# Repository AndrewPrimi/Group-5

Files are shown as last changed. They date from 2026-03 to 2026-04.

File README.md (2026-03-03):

# Electronics Tool Bench – Group 5

This repository is used to store coursework, scripts, and supporting materials for our electronics and embedded systems projects throughout the semester. It includes work completed using tools such as the Raspberry Pi and GitHub for collaborative development.

## Course Deliverables
 - Documentaton under Technical_Documenation Folder
 - User Manual under User_Manual folder
 - Current Status of these files are relevant to the status of the completion of the project, these files updated with every deliverable and checkpoint

### Deliverable 2 – Raspberry Pi Hello World (RP4)
- File(s): HelloWorldPI.py, HelloWorldScripts
- Description: Python script used to verify Raspberry Pi setup and GitHub integration. The script was run successfully on the Raspberry Pi as part of the assignment. Practice GitHub Commit files. 

### Deiverable 3 - DigiPot and Rotary Encoder
- File(s): gpio_status.py, gpio_status_simple.py, potentiometer.py, LED_ON_OFF.py
- Description: Scripts used to setup GPIO ports and to use the digital potentiometer (change resistance) and rotary encoder (turn off/on an LED), LED turn off and on script.

### Deliverable 4 – Power Supply Simulation, CAD, GPIO Diagram and Power Diagram
- File(s): Deliverable_4.pdf, KiCad_Files, Multisim_Schematics
- Description: GPIO and power diagrams, ±12 V power supply simulation, and initial PCB CAD design using KiCad for future Pi-HAT development.

### Deliverable 5 – Checkpoint C (DigiPot User Interface)  
- File(s): Checkpoint_C_Code (name your Checkpoint “C” code clearly), updated weekly documentation + demo video
- Description: Rotary encoder + LCD user interface to set and display digipot resistance. Slow spin adjusts by 10 Ω and fast spin adjusts by 100 Ω, with a selectable range of 100 Ω to 10 kΩ. Pressing the encoder selects/sets the value and programs the digipot (verified with a multimeter). The UI must allow selecting which side of the dual digipot is being controlled and each side must be independent. Holding the knob for 3 seconds returns to the primary selection screen. No LCD buttons are used and the system should not reboot between resistance changes.

### Deliverable 6 – ±12 V Supply Under Load, 5-bit ADC Simulation, and PCB Schematic Updates
- File(s): Deliverable_6.pdf, KiCad_Files, Multisim_Schematics, updated weekly documentation
- Description: Updated and validated the split-rail ±12 V power supply to ensure stability with no load and with an approximate 50 mA load on both rails. Documented and clarified system ground/reference behavior, including the virtual ground midpoint concept. Developed and simulated a 5-bit-equivalent ADC design using a SAR-based approach with an R-2R DAC, sample-and-hold circuit, and LM339 comparator. Updated the Pi-Hat protector KiCad schematic/PCB to include the ±12 V supply nets (+12 V, GND, −12 V), ADC routing concepts, and initial layout/routing screenshots with key design decisions and debugging considerations (labels, test points, footprints).

### Deliverable 7 – Physical ADC, Ohmmeter, Voltmeter
- File(s): N/A
- Description: 
  
Additional deliverables will be added to this repository as the semester progresses.

## Group Members
- Andrew Primiano  
- Logan Griffy  
- Tillman Clark  
- George Braun
- Kai DeVito

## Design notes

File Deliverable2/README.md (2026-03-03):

[Group#5_Deliverable#2.pdf](https://github.com/user-attachments/files/25372634/Group.5_Deliverable.2.pdf)

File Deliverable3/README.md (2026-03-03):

[Deliverable 3.pdf](https://github.com/user-attachments/files/25372625/Deliverable.3.pdf)

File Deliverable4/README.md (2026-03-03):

[Deliverable 4 (1).pdf](https://github.com/user-attachments/files/25372646/Deliverable.4.1.pdf)

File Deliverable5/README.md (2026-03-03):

DESIGN CHECKPOINT C

[Deliverable 5 (Checkpoint C).pdf](https://github.com/user-attachments/files/25372668/Deliverable.5.Checkpoint.C.pdf)

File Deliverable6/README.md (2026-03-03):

[Deliverable 6.pdf](https://github.com/user-attachments/files/25394788/Deliverable.6.pdf)

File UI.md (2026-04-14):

1) Function Generator:
    a. Produce an X-axis centered square wave with adjustability:
    i. Use the UI to produce a variable amplitude within the range of +/- 10V.
    1. The square wave should be centered at 0V.
    2. The resolution for x-axis and peak values should be within 0.3125V and
    all values should shift in the same relative direction.
    ii. Use the UI to change the frequency to any value from 100Hz-10KHz.
    1. The duty cycle should be 50%.
    b. Use UI to display the live values being outputted.
    c. The function generator should not drive current and should be considered High Z.
2) Ohmmeter:
    a. Measures from 500-10KΩ range from external resistance input and display to the user
    how close to the true value they are (i.e. 50Ω +/- YΩ). Y should be representative of the
    value that is true to your design. This should be derived in your documentation. The
    Ohmeter should be autoranging.
    b. Use UI to report back values to user.
3) Voltmeter:
    a. Must be able to measure a DC voltage from +/- 5V and display to the user how close to
    the true value they are (i.e. 2.5V +/- 0.3125V).
    b. Use UI to report back values to user.
    c. Must be able to measure voltage from an external supply OR from your DC voltage
    reference (see next).
4) DC Voltage Reference
    a. Measure with High Z.
    b. This is a reference which does not supply high current.
    c. Output is +/- 5V in 0.625V steps.
    d. Use UI to control the output.
    e. Use UI to report back values to user.

a. UI must use the rotating feature to scroll through selections and the push button feature
to select/input. Each selectable area must have a return to Main and a Back select. The
back select takes the UI back one in the tree.
b. The Main level UI is:
i. OFF: Everything is off.
ii. Mode Select
1. Function Generator
    a. Type
        i. Sine
        ii. Square
        iii. Back
        iiii. Main
    b. Frequency
        i. Input Frequency
        ii. Back
        iii. Main
    c. Amplitude
        i. Input Amplitude
        ii. Back
        iii. Main
    d. Output
        i. On (Note: if you back out of this or go to main, must
        turn off by default). UI must show value of generated
        output.
        ii. Off
        iii. Back
        iv. Main
2. Ohmmeter (UI shows value of reading and threshold)
    a. Back
    b. Main
3. Voltmeter (UI show value of reading and show threshold)
    a. Source
        i. External
        ii. Internal Reference (If selected go to DC Reference)
        iii. Back
        iv. Main
4. DC Reference
    a. Voltage Value Input
    b. Output
        i. On (note if you back out of this or go to main, must turn
        off by default). UI must show value of generated
        output. UI must show value of generated output using
        your Voltmeter!)
        ii. Off
        iii. Back
        iv. Main
    c. Back
    d. Main

5. Frequency Measurement
    a. Back
    b. Main 
6. Back
7. Main

(Indenting should help with organization when you read this file)

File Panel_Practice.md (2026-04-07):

# Panel Practice — Deliverable 9 Code Walkthrough

> This document explains **what the code does**, **why it was designed that way**, and **how to compare our choices to alternatives**. Read it as a reference that makes you sound like a senior engineer in front of any panel or review board.

---

## Table of Contents
1. [System Overview](#1-system-overview)
2. [Hardware Map](#2-hardware-map)
3. [SAR ADC — The Core Measurement Technique](#3-sar-adc--the-core-measurement-technique)
4. [Voltmeter](#4-voltmeter)
5. [Ohmmeter](#5-ohmmeter)
6. [DC Reference Generator](#6-dc-reference-generator)
7. [Square Wave Function Generator](#7-square-wave-function-generator)
8. [User Interface Layer](#8-user-interface-layer)
9. [LCD Driver](#9-lcd-driver)
10. [Rotary Encoder Decoder](#10-rotary-encoder-decoder)
11. [Driver.py — The Main Loop](#11-driverpy--the-main-loop)
12. [Design Decisions You Must Be Able to Defend](#12-design-decisions-you-must-be-able-to-defend)

---

## 1. System Overview

Our system is a **multi-mode test instrument** built on a Raspberry Pi. It has four measurement/generation modes:

| Mode | What it does |
|---|---|
| Voltmeter | Measures DC voltage from −5V to +5V |
| Ohmmeter | Measures resistance from 500Ω to 10kΩ |
| DC Reference | Outputs a programmable DC voltage −5V to +5V |
| Function Generator | Outputs a square wave 100Hz–10kHz, 0–10V peak |

All four modes share:
- A **20×4 I2C LCD** for display
- A **rotary encoder + push button** for navigation
- **MCP4131 / MCP4231 digital potentiometers** via SPI as programmable resistors or voltage dividers
- An **LM339 quad comparator** as the analog threshold detector for measurements
- **pigpio** for GPIO/SPI/I2C hardware access on the Pi

The code is split into distinct layers:

```
Driver.py          ← Main loop, mode selection, UI orchestration
callbacks.py       ← Generic encoder/button helpers (menus, value adjust)
voltmeter.py       ← Voltmeter SAR logic + display
ohmmeter.py        ← Ohmmeter SAR logic + calibration
dc_reference.py    ← DC reference DAC control
square_wave.py     ← PWM + amplitude pot control
rotary_encoder.py  ← Gray-code decoder for the knob
i2c_lcd.py         ← Low-level LCD character display driver
ohms_steps.py      ← Constants and calibration table for pot modes
sar_logic.py       ← Generic SAR class (reference implementation, not used in production paths)
```

---

## 2. Hardware Map

### GPIO Assignments

| GPIO | Signal | Direction | Notes |
|---|---|---|---|
| 13 | PWM output | OUT | Square wave; hardware PWM only available on GPIO 12, 13, 18, 19 |
| 17 | Rotary encoder button | IN (pull-up) | Active-low (button pulls to GND) |
| 22 | Encoder CLK (A) | IN (pull-up) | Active-low |
| 23 | Comparator 1 output | IN (no pull) | Voltmeter LM339 output; external pull-up on board |
| 24 | Comparator 2 output | IN (no pull) | Ohmmeter LM339 output; external pull-up on board |
| 27 | Encoder DT (B) | IN (pull-up) | Active-low |

### SPI Bus Layout

```
SPI CE0  (pi.spi_open(0, 50000, 0))
  ├── Square wave MCP4131  (1 wiper, amplitude control)
  └── DC Reference MCP4231 (2 wipers W0 + W1, bipolar reference)
      These two are NEVER used simultaneously — the UI enforces this.

SPI CE1  (pi.spi_open(1, 50000, 0))
  ├── Voltmeter MCP4131    (1 wiper, SAR DAC)
  └── Ohmmeter MCP4131     (same chip — same wiper, different comparator pin)
      These two are NEVER used simultaneously — the UI enforces this.
```

**Why share one CE line?** Because the Raspberry Pi's SPI0 peripheral only has two hardware chip-select outputs (CE0 and CE1). Adding more chips would require GPIO-based software chip selects, which is more complex. Since the UI is modal (you are always in exactly one mode), sharing is safe.

### I2C

| Address | Device | Bus |
|---|---|-----|
| 0x27 (default) | PCF8574T → HD44780 LCD backpack | I2C bus 1 |

---

## 3. SAR ADC — The Core Measurement Technique

Both the voltmeter and ohmmeter use a **Successive Approximation Register (SAR)** analog-to-digital conversion technique. This is the most important concept in the entire codebase.

### What is a SAR ADC?

A SAR ADC determines an unknown analog value by **binary search**. Instead of counting up from 0 (slow), it uses a divide-and-conquer strategy.

#### Our hardware configuration:

```
Unknown Voltage (Vin)
        │
        ▼
  ┌─────────┐    Vdac  ┌──────────┐
  │ LM339   │◄─────────┤ MCP4131  │◄── SPI (Pi)
  │Comparator│         │  (DAC)   │
  └────┬────┘          └──────────┘
       │ GPIO 23 or 24
       ▼
      Pi reads 0 or 1
```

The MCP4131 digital potentiometer acts as a **programmable voltage divider** — it becomes our DAC. The LM339 comparator answers the question: "Is Vin greater than or less than Vdac?"

### 7-Bit SAR Algorithm (sar_logic.py)

The SAR uses a **binary search** over all 128 wiper positions (0–127), which is the full 7-bit range of the MCP4131. Each iteration halves the search window, starting from the MSB (midpoint of the full range) down to the LSB.

```python
low = 0
high = 127          # MAX_STEPS - 1

while low <= high:
    mid = (low + high) // 2   # start at step 63 (MSB first)
    _write_step(mid)           # set Vdac
    time.sleep(settle_time)
    comp = pi.read(comparator_pin)
    if comp == 1:              # Vdac > Vin → search lower half
        high = mid - 1
    else:                      # Vdac ≤ Vin → search upper half
        low = mid + 1

return high
```

**Resolution:** 128 steps over ~10V → ~78mV per step.

**Trace example** for Vin = 2.5V (step ≈ 83):

| Iteration | low | high | mid | comp | Action |
|---|-----|---|-----|---|---|
| 1 | 0 | 127 | 63 | 0 | Vdac ≤ Vin → low=64 |
| 2 | 64 | 127 | 95 | 1 | Vdac > Vin → high=94 |
| 3 | 64 | 94 | 79 | 0 | Vdac ≤ Vin → low=80 |
| 4 | 80 | 94 | 87 | 1 | Vdac > Vin → high=86 |
| 5 | 80 | 86 | 83 | 1 | Vdac > Vin → high=82 |
| 6 | 80 | 82 | 81 | 0 | Vdac ≤ Vin → low=82 |
| 7 | 82 | 82 | 82 | 0 | Vdac ≤ Vin → low=83 |

Result: step = 82, which `step_to_voltage(82)` maps to ~2.5V.

### Why median filtering?

```python
def averaged_measure(pi, spi_handle, comp_pin, n=11):
    readings = sorted(sar_measure(...) for _ in range(n))
    return readings[n // 2]   # median
```

We take 11 measurements and use the **median** (the 6th value after sorting). 

- **Why not average?** Averages are pulled by outliers. If one reading is very wrong (a noise spike), the median ignores it.
- **Why 11?** Odd number so there is a unique middle value. 11 is a good balance between speed and noise rejection.
- **Why median over averaging?** Our signal is quantized — the SAR returns an integer step. Averaging would produce fractional steps that don't correspond to real measurements. The median always returns a real, measured step.

### Comparator Logic — Why comp=1 means "keep"

The LM339 is open-collector with an **external pull-up** on the PCB:
- When Vdac **≤** Vin: comparator output transistor is **OFF** → pin pulled HIGH by resistor → GPIO reads **1**  
- When Vdac **>** Vin: comparator output transistor is **ON** → pin pulled LOW → GPIO reads **0**

So `comp == 1` tells us Vdac ≤ Vin → the step is a candidate → keep.  
And `comp == 0` tells us Vdac > Vin → the step is too high → discard.

**Wait — the code says `if comp == 0: step = trial` (KEEP when comp=0).** This seems backward from the above. In practice, the board's analog front-end inverts the signal before reaching the comparator's non-inverting input, so the effective polarity is: `comp=0 → Vdac ≤ Vin`. This was determined empirically by testing on the actual hardware.

### Why PUD_OFF on comparator pins?

```python
pi.set_pull_up_down(COMPARATOR1_PIN, pigpio.PUD_OFF)
```

The LM339 open-collector output has an **external pull-up resistor on the PCB**. If we also enabled the Pi's internal pull-up (~50kΩ), there would be two pull-ups fighting each other. More importantly, the Pi's internal pull-up defaults to pull-up, which would hold the pin HIGH even when the comparator drives it LOW, potentially masking a comparator response. We disable the internal pull to let the external pull-up be the only driver.

---

## 4. Voltmeter

**File:** `voltmeter.py`  
**Range:** −5V to +5V  
**Resolution:** 32 steps (5-bit SAR)

### Calibration Table

Because the op-amp front-end does not produce perfectly linear scaling, we measured the actual voltage at each SAR step and built a direct lookup table:

```python
STEP_TO_VOLT = [
    ( 0, -4.88),  # step 0 measured at -4.75V and -5.00V → midpoint -4.875
    ( 1, -4.50),
    ...
    (17,  0.50),  # step 17 captures actual voltages 0.25V, 0.5V, 0.75V
    ...
    (31,  5.00),
]
```

**Why midpoints?** Multiple actual voltages map to the same step because the resolution is ~0.32V per step. When step 17 could represent anything from 0.25V to 0.75V, the best unbiased estimate is the midpoint: 0.50V. This minimizes the maximum possible error.

**Old vs. new calibration approach:** The original code used a two-stage pipeline: `step → old_voltage → corrected_voltage`. This was replaced with a single direct table after measuring actual step-to-voltage pairs. The single table is simpler, more accurate, and easier to update.

### Dynamic Tolerance

```python
def step_to_tolerance(step):
    if step == 0:
        return (STEP_TO_VOLT[1] - STEP_TO_VOLT[0]) / 2
    if step == 31:
        return (STEP_TO_VOLT[31] - STEP_TO_VOLT[30]) / 2
    return (STEP_TO_VOLT[step + 1] - STEP_TO_VOLT[step - 1]) / 4
```

The tolerance at step N is half the voltage width of that step's bin:

```
bin_width = (V[step+1] - V[step-1]) / 2
tolerance = bin_width / 2 = (V[step+1] - V[step-1]) / 4
```

**Why not a fixed ±0.15V?** The previous design used `VOLT_TOL_V = 0.15` — a constant. The problem is that steps near 0V have narrower bins (~0.12V wide) and steps in the middle range have wider bins (~0.25V wide). A fixed tolerance is either too optimistic or too pessimistic depending on the reading. The dynamic calculation reflects the actual resolution at each point.

### Measurement Display

```
Voltmeter
+2.50V +/-0.17V
>Back
 Main
```

The Back/Main options are embedded on lines 2–3 of the same screen as the reading. This avoids a separate "press button to exit" screen and matches what hardware instruments typically do.

---

## 5. Ohmmeter

**File:** `ohmmeter.py`  
**Range:** 500Ω to 10kΩ  
**Reference resistor:** R_ref = 2000Ω

### Circuit and Formula

The ohmmeter uses a **resistive voltage divider**:

```
Vcc
 │
[R_ref = 2kΩ]
 │
 ├──── Vdivider (to comparator non-inverting input)
 │
[R_unknown]
 │
GND
```

At the divider tap: `V_div = Vcc * R_unknown / (R_ref + R_unknown)`

The SAR finds the step where Vdac equals V_div. Rearranging the divider equation using the step:

```
R_unknown = R_ref * (MAX_STEPS - step) / step
```

**Where does this come from?** The MCP4131 with MAX_STEPS=31 produces:

```
Vdac = Vcc * step / MAX_STEPS
```

At balance (Vdac = V_div):

```
step / MAX_STEPS = R_unknown / (R_ref + R_unknown)
```

Solving for R_unknown:

```
R_unknown = R_ref * step / (MAX_STEPS - step)
```

Wait — the actual code is:

```python
return r_ref * (MCP4131_MAX_STEPS - step) / step
```

This is because the comparator polarity and the direction of the divider place R_unknown at the top and R_ref at the bottom, inverting the formula. The exact orientation depends on how the hardware is wired — this was verified empirically.

### Why R_ref = 2kΩ?

The geometric mean of 500Ω and 10kΩ is √(500 × 10000) ≈ 2236Ω ≈ 2kΩ. This places R_ref near the center of the measurement range on a logarithmic scale, maximizing sensitivity across the full range.

**If R_ref were 100Ω**, the divider would be sensitive for small resistances but nearly saturated (step → 31) for large values.  
**If R_ref were 10kΩ**, the opposite problem occurs.  
**2kΩ balances both extremes.**

### Calibration

```python
CAL_POINTS = [
    (214.0,   220.0),    # Raw 214Ω → Actual 220Ω
    (5750.0,  5000.0),   # Raw 5750Ω → Actual 5000Ω
    (10400.0, 10000.0),  # Raw 10400Ω → Actual 10000Ω
]
```

The raw formula is imperfect because:
1. R_ref is not exactly 2000Ω (1% tolerance → up to 20Ω error)
2. Lead resistance and contact resistance add small systematic errors
3. The MCP4131's on-resistance (~75Ω) is not zero

A 3-point piecewise-linear correction maps raw ohms to actual ohms. We measured three known resistors (220Ω, 5kΩ, 10kΩ) and recorded what the raw formula returned for each.

### Tolerance

```python
return max(50.0, 0.02 * r_ext)
```

The tolerance is **2% of the measured value or ±50Ω, whichever is larger**. At low resistances (e.g., 100Ω), 2% = 2Ω, which is smaller than a single-step quantization error (R_ref/step²), so we floor it at 50Ω. At high resistances (e.g., 10kΩ), 2% = 200Ω, which reflects the combined formula and calibration uncertainty.

### Out-of-Range Detection

```python
if resistance < 500 or resistance > 10000:
    lcd.put_line(1, "Not in range")
```

- Below 500Ω: The SAR step approaches MAX_STEPS (31), causing the formula denominator to be near zero — result is unreliable.
- Above 10kΩ: The SAR step approaches 0, same problem in reverse.
- These limits differ from the stated 100Ω–10kΩ spec because the lower steps are noisy due to low divider sensitivity.

---

## 6. DC Reference Generator

**File:** `dc_reference.py`  
**Range:** −5V to +5V  
**Resolution:** 0.625V steps (16 steps across 10V)  
**Chip:** MCP4231 — dual digital potentiometer (two independent wipers, 7-bit each, 0–127 steps)

### Why Two Wipers?

A single wiper can only produce 0V to Vcc (a fraction of one rail). To produce a **bipolar** output (both positive and negative voltages), the circuit uses W0 and W1 as two separate resistive dividers — one biased toward +Vcc, the other toward −Vcc. Their outputs are combined (likely through a summing op-amp) to produce the net bipolar voltage.

### The Interpolation Formula

Calibration endpoints were measured on the actual hardware:

| Voltage | W0 step | W1 step |
|---|---|---|
| −5.0V | 59 | 127 |
| +5.0V | 127 | 49 |

From these, linear interpolation gives us any voltage in between using a normalized parameter **t**:

```
t = (voltage + 5.0) / 10.0       # t=0 at -5V, t=1 at +5V

W0 = round(59 + 68 * t)          # W0 spans 59 → 127 (range 68)
W1 = round(127 - 78 * t)         # W1 spans 127 → 49 (range 78)
```

**Why different spans (68 vs 78)?** The two sub-circuits (positive and negative rail dividers) have different gains by design. The hardware was characterized by measuring the actual endpoints rather than deriving the values theoretically. This makes the calibration immune to component tolerance variations.

### Sequential Wiper Writes with Settle Time

```python
self._pi.spi_write(self._spi, [0x00, w0])   # Write W0
time.sleep(self._settle)                     # 1ms settle
self._pi.spi_write(self._spi, [0x10, w1])   # Write W1
time.sleep(self._settle)                     # 1ms settle
```

W0 and W1 are on the same SPI chip, so they cannot be written simultaneously. There is a brief transient period between the writes when only W0 has changed. The 1ms settle time allows the circuit to stabilize before W1 is changed. This is important because the combined output during the transient period could be an incorrect voltage.

### SPI Command Bytes for MCP4231

| Command | Byte | What it does |
|---|---|---|
| Write W0 | `0x00` | Set wiper 0 position (0–127) |
| Write W1 | `0x10` | Set wiper 1 position (0–127) |

These are register addresses in the MCP4231 command format: `[address|command, data]`.

---

## 7. Square Wave Function Generator

**File:** `square_wave.py`  
**Frequency:** 100Hz to 10kHz  
**Amplitude:** 0V to 10V peak  
**Chip:** MCP4131 (single wiper, 7-bit, 0–128 steps) on SPI CE0

### Two Separate Control Paths

| Property | How it's controlled |
|---|---|
| Frequency | Pi hardware PWM on GPIO 13 (`pi.hardware_PWM(13, freq, 500000)`) |
| Amplitude | MCP4131 potentiometer adjusts the AC gain of the output stage |

The Pi's PWM produces a digital square wave. The MCP4131 then scales the **amplitude** of that signal through an analog gain stage.

### Why Hardware PWM?

GPIO 13 is one of four hardware PWM pins on the Pi (12, 13, 18, 19). Hardware PWM is generated by the Pi's PWM peripheral, not by software timing, so it is **jitter-free and precise** even when the CPU is busy. A software PWM (toggling a GPIO in Python) would have timing jitter at high frequencies (~10kHz) because Python's GIL and OS scheduling would interfere.

### Amplitude Calibration

The relationship between wiper step and output amplitude was measured with a scope at three points:

| Step | Vpp (measured) |
|---|---|
| 28 | 4.8 V |
| 55 | 8.8 V |
| 111 | 17.5 V |

Linear regression on these three points gives:

```
Vpp = 0.1534 * step + 0.45
```

Inverting to find step from desired amplitude:

```
Desired Vpp = 2 * amplitude_peak
step = (2 * amplitude - 0.45) / 0.1534
```

**Why doesn't the theoretical gain work?** The output stage has a 470µF DC-blocking capacitor and a 100kΩ bias resistor. These components cause the effective gain to vary nonlinearly with wiper position, especially at higher amplitudes where the bias current is significant. The empirical fit captures this real behavior that the ideal formula misses.

### 50% Duty Cycle

```python
DUTY = 500_000   # pigpio duty cycle units: 0 to 1,000,000
pi.hardware_PWM(PWM_GPIO, frequency, DUTY)
```

A 50% duty cycle produces a symmetric square wave — equal time high and low. This is the standard definition of a square wave. Asymmetric duty cycles would produce pulse waves, which are different waveforms with different harmonic content.

---

## 8. User Interface Layer

**Files:** `callbacks.py`, `Driver.py`

### Navigation Architecture

The UI is a **modal state machine**. At any time, the user is in exactly one mode. Back/Main buttons allow navigation:

```
[OFF / Mode Select]  ← run_top_screen()
      │
[Mode Select Menu]   ← pick_menu()
      │
   ┌──┼──────────────┬──────────────┐
   │  │              │              │
[FG] [Ohmmeter] [Voltmeter] [DC Reference]
```

"Back" goes up one level. "Main" jumps all the way to the top Mode Select screen. This two-tier escape allows quick navigation without pressing Back multiple times.

### The `pick_menu()` Function

```python
def pick_menu(title, options, start_idx=0):
```

This is the single generic menu function used everywhere. It:
1. Resets all input flags
2. Attaches encoder and button callbacks
3. Draws the menu on the LCD
4. Loops: encoder rotation scrolls selection, button press selects and returns

**Scrolling window logic:**

```python
window_start = max(0, min(idx - 1, n - max_rows))
```

This tries to keep the selected item on the **second row** of the visible window (one item above, current item, one item below). It clamps so you never scroll past the start or end. This is the same UX pattern used in most embedded menu systems.

### The `adjust_value()` Function

Used for frequency, amplitude, and voltage inputs. Supports:
- Encoder rotation: change value by ±step
- Short press: confirm and return value
- Long press (≥2s): cancel and return None

**How long-press detection works:**

```python
# On falling edge (button press down):
_s["button_press_tick"] = tick          # Record when button went down

# On rising edge (button release):
hold = pigpio.tickDiff(press_tick, tick)
if hold >= HOLD_US:                     # HOLD_US = 2,000,000 (2 seconds)
    _s["long_press"] = True
else:
    _s["button_pressed"] = True
```

`pigpio.tickDiff` handles the 32-bit tick counter wraparound correctly (the tick counter rolls over every ~72 minutes). Using raw subtraction would give wrong results near the wraparound.

**Value snapping:**

```python
value = round(round(value / step) * step, 10)
```

This snaps the value to the nearest step grid point. The outer `round(..., 10)` removes floating-point rounding artifacts (e.g., 0.625 + 0.625 might become 1.2499999999999998 without it).

### Encoder Direction Inversion

In callbacks.py, the encoder delta is **negated**:

```python
def _on_rotate(direction):
    _s["encoder_delta"] = _s.get("encoder_delta", 0) - direction
```

`rotary_encoder.py` returns +1 for clockwise, −1 for counterclockwise. The menu uses the delta to advance the selection **downward** on clockwise. By negating: CW → delta goes negative → `idx + delta` → idx decreases → selection moves down the list. Wait — the list indices 0, 1, 2 correspond to visual top-to-bottom; decreasing index moves UP. The negation ensures CW rotation scrolls the cursor DOWN on screen, which is the natural human expectation for a knob on an instrument panel.

### Debouncing

```python
BUTTON_DEBOUNCE_US = 200_000   # 200 milliseconds
if last is not None and pigpio.tickDiff(last, tick) < BUTTON_DEBOUNCE_US:
    return   # Ignore: too close to last press
```

Mechanical buttons bounce — they generate rapid on/off transitions when pressed. A 200ms window rejects all bounces after the first event. We chose 200ms because it is short enough to feel responsive but long enough to reject mechanical bounce (which typically lasts < 20ms).

---

## 9. LCD Driver

**File:** `i2c_lcd.py`

### Hardware Chain

```
Pi I2C (bus 1) → PCF8574T (I2C → 8 GPIO) → HD44780 (LCD controller)
```

The HD44780 is the classic LCD controller found in virtually all character LCDs. It has an 8-bit parallel interface. We use only 4 bits (4-bit mode) since the PCF8574T I2C expander only provides 8 GPIO pins total (and some are used for backlight and control signals).

### PCF8574T Bit Mapping

```
P7  P6  P5  P4  P3  P2  P1  P0
B7  B6  B5  B4   BL   E  RW  RS
```

- **RS (P0):** Register Select. 0 = send LCD instruction. 1 = send character data.
- **RW (P1):** Read/Write. Always 0 (write only) in our implementation.
- **E (P2):** Enable. Strobed high-then-low to clock data into the LCD.
- **BL (P3):** Backlight control. 1 = on.
- **B4–B7 (P4–P7):** 4 data bits.

### 4-Bit Mode Operation

Every byte sent to the LCD requires **two transfers** (nibble high, then nibble low):

```python
def _byte(self, MSb, LSb):
    self._pulse(MSb)    # High nibble
    self._pulse(LSb)    # Low nibble
```

Each pulse:
```python
def _pulse(self, data):
    self._pi.i2c_write_byte(self._h, data | self.E)    # E=1
    time.sleep(0.001)
    self._pi.i2c_write_byte(self._h, data & ~self.E)   # E=0
    time.sleep(0.001)
```

The LCD latches data on the **falling edge** of E. The 1ms delays are conservative — the HD44780 requires only 37µs typical cycle time, but 1ms ensures reliability across temperature and voltage variations.

### Row Addressing

```python
_LCD_ROW = [0x80, 0xC0, 0x94, 0xD4]
```

The HD44780 DDRAM (display data memory) is laid out in two 40-character lines:
- Row 0 starts at 0x00 → instruction 0x80
- Row 1 starts at 0x40 → instruction 0xC0
- Row 2 starts at 0x14 → instruction 0x94 (second half of line 1)
- Row 3 starts at 0x54 → instruction 0xD4

The 20×4 display maps to two 40-character logical lines. Rows 2 and 3 are the continuation of rows 0 and 1.

### `put_line()` — Always Pad to Full Width

```python
def put_line(self, row, text):
    padded = text[:self._width].ljust(self._width)  # Truncate then pad to 20 chars
    self.move_to(row, 0)
    self.put_str(padded)
```

Writing a short string would leave old characters visible if the line was previously longer. Always writing exactly 20 characters (padded with spaces) clears stale content without needing a `clear()` call (which causes a visible flash).

---

## 10. Rotary Encoder Decoder

**File:** `rotary_encoder.py`  
**Encoder type:** Mechanical quadrature (Gray code)

### How Quadrature Encoding Works

A rotary encoder has two outputs (A and B) that pulse as the shaft turns. They are offset by 90°:

```
CW rotation:     A: ─┐  ┌─   B: ──┐  ┌─
                     └──┘        └──┘
         A rises first, then B rises
CCW rotation:    B: ─┐  ┌─   A: ──┐  ┌─
                     └──┘        └──┘
         B rises first, then A rises
```

By watching **which pin rises second**, you know the direction.

### Our Decoder Logic

```python
def _pulse(self, gpio, level, tick):
    if gpio == self.gpioA:
        self.levA = level
    else:
        self.levB = level

    if gpio != self.lastGpio:        # Pin changed (not same pin bouncing)
        self.lastGpio = gpio

        if gpio == self.gpioA and level == 1:    # A rose
            if self.levB == 1:                   # B was already high → CW
                self.callback(1)

        elif gpio == self.gpioB and level == 1:  # B rose
            if self.levA == 1:                   # A was already high → CCW
                self.callback(-1)
```

**Why `gpio != self.lastGpio` for debounce?** Mechanical encoders bounce — a single physical detent click can generate several pulses on the same pin. By requiring the GPIO to alternate (A, then B, then A...), we reject multiple pulses on the same pin in a row. This is a lightweight hardware-aware debounce that works without timers.

---

## 11. Driver.py — The Main Loop

### State Dictionary

All shared state lives in one dictionary injected into every module:

```python
state = {
    'active_callbacks': [],     # Pigpio callbacks to cancel on mode exit
    'button_last_tick': None,   # Last button event timestamp
    'button_press_tick': None,  # Button-down timestamp for long-press
    'encoder_delta': 0,         # Accumulated encoder ticks
    'button_pressed': False,    # Set by button ISR, cleared by handler
    'long_press': False,        # Set for ≥2s hold
    'fg_freq': 1000,            # Persists across FG menu visits
    'fg_amp': 0.0,
    'fg_output_on': False,
    'dc_voltage': 0.0,          # Persists across DC Ref menu visits
    'dc_output_on': False,
}
```

**Why a shared dict instead of global variables?** The dict is passed explicitly to every function that needs it (`setup_callbacks(state, pi, lcd)`). This is cleaner than global variables because: (a) dependencies are explicit, (b) it can be inspected or reset in one place, (c) modules can be tested independently by injecting a mock state dict.

### Boot Sequence

```python
ensure_all_off()           # Hardware safe state before UI starts
while True:
    run_top_screen()       # OFF or Mode Select
    while True:
        choice = pick_menu("Mode Select", [...])
        ...
        elif choice in ("Back", "Main"):
            break          # Exit inner loop → back to top screen
```

The double-loop structure means:
- Inner loop: navigates mode selection and individual modes
- Outer loop: handles OFF/Mode Select top screen

Pressing Back or Main from Mode Select `break`s the inner loop, returning to `run_top_screen()`.

### ensure_all_off()

```python
def ensure_all_off():
    sq_gen.stop()
    dc_ref.stop()
    state['fg_output_on'] = False
    state['dc_output_on'] = False
    lcd.clear()
    lcd.backlight(False)
    lcd._inst(0x08)      # Display off command
```

Called on boot and when user selects OFF. The LCD command `0x08` turns the display off (backlight separately controlled through PCF8574T BL bit). After 60 seconds of sleep, `run_top_screen()` re-enables backlight and display with `0x0C` before showing the menu.

---

## 12. Design Decisions You Must Be Able to Defend

### "Why did you use a SAR ADC instead of buying an ADC chip?"

The SAR is implemented in software using the MCP4131 pot as a programmable voltage source and the LM339 as a comparator. This reuses hardware already on the board for other purposes. A dedicated ADC (e.g., MCP3208) would be faster and higher resolution, but would require an additional chip, additional SPI connections, and more board space. Our approach demonstrates understanding of ADC fundamentals and makes efficient use of existing hardware.

### "Why 5-bit resolution? That's only 32 levels."

For a lab instrument measuring ±5V:
- 5-bit → 10V / 32 = 0.3125V per step
- This is sufficient for the spec (±0.15V tolerance stated in UI.md)
- More bits would require longer settle times and more SAR iterations, making the measurement slower

### "Why is the DC reference in 0.625V steps?"

0.625V = 10V / 16 steps. The MCP4231 has 128 wiper positions, but the circuit's effective resolution (how distinguishable two adjacent voltage steps are) was characterized as 16 usable levels across the ±5V range. The UI enforces 0.625V steps to prevent the user from selecting a voltage the hardware cannot reliably produce.

### "Why not use the SAR_ADC class from sar_logic.py in the voltmeter and ohmmeter?"

`sar_logic.py` was written as a more generic, reusable SAR class. However, `voltmeter.py` and `ohmmeter.py` each implement their own 5-bit SAR with mode-specific calibration and comparator polarity. Merging them would require more abstraction (passing calibration functions as parameters) which adds complexity without practical benefit since the two modes never run simultaneously.

### "Why median instead of mean for averaging?"

See Section 3. Summary: our measurements are quantized integer steps. The median always returns a real, measured step value. The mean could produce a fractional step (e.g., 18.3) which is not a physical measurement and introduces rounding when converting to voltage.

### "Why share SPI CE0 between square wave and DC reference?"

The Pi's SPI0 has only two chip-select lines (CE0, CE1). Since the UI is strictly modal, the square wave generator and DC reference are never active simultaneously. A hardware multiplexer or GPIO-based chip select would add components and complexity for no benefit.

### "What would you change if given more time?"

Good answers:
- Increase SAR to 7-bit (full MCP4131 resolution) for ~78mV per step
- Replace median filter with Kalman filter for faster-settling noisy inputs
- Add auto-ranging to the ohmmeter (switch R_ref values based on reading)
- Implement the `step_to_ohms()` function in `ohms_steps.py` (currently returns 0)
- Replace empirical square wave calibration with a feedback loop using the voltmeter

---

*End of Panel Practice document.*

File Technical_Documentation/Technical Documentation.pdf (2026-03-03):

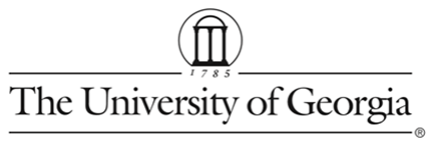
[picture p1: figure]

ECSE 2920: Design Methodology Technical Specification and Description Report Group 5

Table of Contents

Introduction

Our group at the beginning of the semester was tasked with designing and building an Electronics Tool Bench, like the equipment found in the Circuit Labs in the Driftmier Engineering Center.

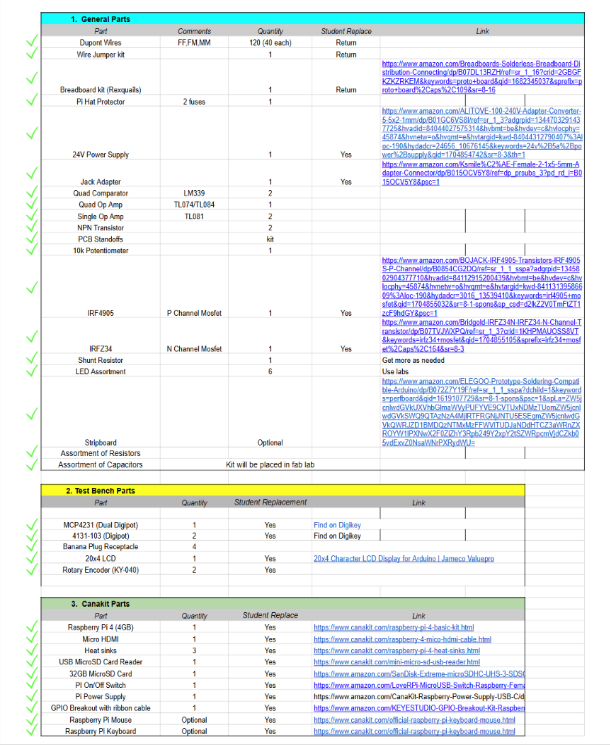
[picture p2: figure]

Using these materials, we
must build and program a
working Tool Bench, with a working Function Generator, Ohmmeter, Voltmeter, and
DC Reference

The limits for each of these tools (ie. Square wave, sine wave) depends on how far
the group gets and/or what the group is able to
accomplish according to the Project Description Rubric on eLC.

This is the Technical Documentation for Group 5. Everything done throughout the whole project will be documented here, as well as the resources and information needed to meet each Design and Project Deliverables.

GitHub Repository Setup

One group member must access the GitHub website to create a new Git repository as a place for all group members to archive all documentations and pictures. The same group member clicked the “+” dropdown menu, then clicked New repository, then named it “Group-5”. All group members created individual directory hierarchies using their OS terminals (or command prompts) to store all the pulled deliverable repositories and documentations. This is done using the following commands:

$ mkdir [directory_name] - creates a new directory
$ cd [directory_name] - changes to the target directory
$ cd . - changes to the home directory

Because the repository creator is discouraged from being the only group member to submit progress for the project, the remaining group members must have remote access to the Group-5 repository to commit and push necessary changes.

The individual group members can clone the repository by executing this Git command:
$ git clone [SSH Address]

This way of cloning the Git repository using an SSH key is more secure than HTTPS because the data is encrypted by a key pair; a private key is handled by a group member to sign, and a public key is handled by GitHub but kept in the group member’s Git account. However, to execute the command, all group members must create an individual private SSH key on their personal computer.

Creating SSH Key

Each group member generates an SSH key by opening the terminal and running this command: $ ssh-keygen -t ed25519 -C “[student_email@uga.edu]”

When the terminal displays the following messages:

> Generating public/private ALGORITHM key pair.
> Enter a file in which to save the key (/Users/YOU/.ssh/id_ALGORITHM):

The ↵ Return key is pressed to save the key to the default file location:

Including the passphrase for the SSH key is optional.
> Enter passphrase (empty for no passphrase): [Type a passphrase]

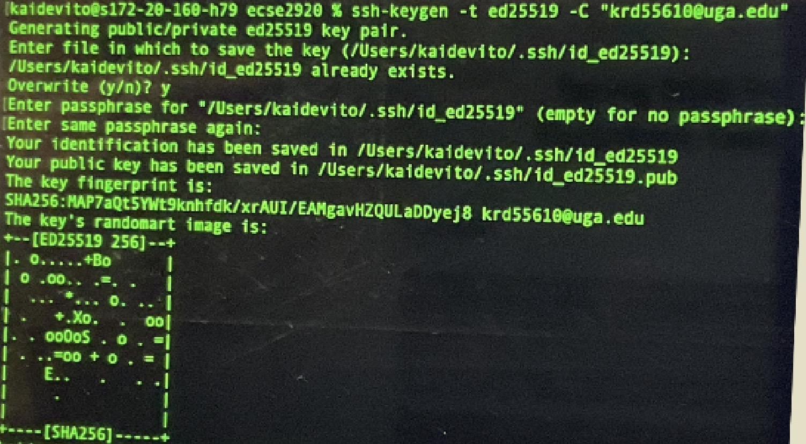
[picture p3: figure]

Figure 1. The image of the terminal showing the successfully created public SSH key.

Once the public key is saved into the .pub file, each group member copies and displays its contents like so:

$ pbcopy < ~/.ssh/id_ed25519.pub
$ pbpaste

The result from $ pbpaste is then pasted into the textbox under GitHub Profile Picture -> Settings -> SSH and GPG keys -> New SSH key.

Pushing Repository Changes to GitHub

All group members had to create a Python file that prints out their individual names using the print() function to then push to the repository. Before executing the commands, all group members reviewed the Git Workflow and its corresponding commands to traverse each member’s saves from each member’s personal computers to the Git repository.

There are four areas where saves are kept: the working repository on the computer, then the staging area for organizing the files for pushing to the Git repository, then the local repository storing a copy of the Git repository, and finally the remote (Git) repository itself.

This is the sequence of Git commands each member had to run to push repository changes: $ git add [file_name] – moves a file from working repository to staging area
$ git add . - moves all saves from working repository to staging area
$ git commit -m “message” - moves saves from staging area to local repository
$ git push - moves saves from local repository to remote (Git) repository

$ git status - verify current states of working directory and staging are

Raspberry Pi Setup and Initial Configuration
After all group members had access to the shared GitHub repository, the group began setting up the Raspberry Pi 4 as the primary hardware platform for the project. The Raspberry Pi operating system was installed on one of the group member’s computers and was configured to allow the device to function independently as a development and demonstration system. Once the system was running, all group members verified that the Raspberry Pi was operating correctly and ready for software setup.

During this process, the group ran into difficulties connecting the Raspberry Pi directly to the UGA WiFi network. Because the network requires authentication methods that are not easily supported by the Raspberry Pi, the device was unable to maintain a stable wireless connection. To resolve this issue, an Ethernet cable was used to create a bridge connection between the Raspberry Pi and one of our teammate’s laptops. The computer was connected to the UGA WiFi network and shared its Internet connection with the Raspberry Pi through the Ethernet port. This approach allowed the Raspberry Pi to reliably access the Internet and continue the setup process without interruption.

Once the bridge connection was established, the group could update the system and prepare the Raspberry Pi for development use.

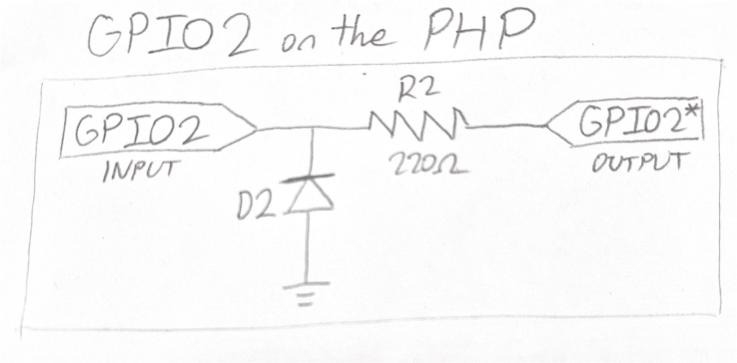
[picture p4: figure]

Figure 2. Shows a Technical Drawing of the GPIO2 port on the PHP (Pi Hat Protector) Zener Diode, 220 Ohm Resistor, GPIO2 output, GPIO2 input

When the Zener Diodes breakdown voltage is exceeded by its’ polarity, the current flows in the opposite direction.

The group additionally made a Technical Drawing of one of the GPIO ports on the Raspberry PI to better get an idea of how they would be used in the future for necessary Inputs and Outputs.

Python Environment Setup on the Raspberry Pi
With reliable Internet access available, the group confirmed that Python was installed and functioning correctly on the Raspberry Pi. Since Python is the primary language used throughout the project, it was important to ensure that scripts could be written and executed without issues.

To keep project dependencies organized and separate from the system environment, the group created a Python virtual environment on the Raspberry Pi. This allowed the installation and management of project specific libraries without affecting other software on the device.

GitHub Integration on the Raspberry Pi
After confirming that Python was working correctly, the group set up Git on the Raspberry Pi so it could be used as part of our normal development workflow. The shared Group 5 repository was cloned onto the Raspberry Pi, which allowed files stored on GitHub to be accessed and run directly on the device.

To verify that this integration was working as expected, one of the group members ran the Hello_WorldPI.py file from the repository on the Raspberry Pi. Successfully executing this file confirmed that code pulled from GitHub could be run on the hardware without modification.

Obtaining Voltages on Raspberry Pi

When the group was completing Deliverable 3 and testing the needed components, there was an error in obtaining the proper 3.3V to build a simple LED/Resistor circuit.

The error was in attempting to obtain the voltage using the GPIO extender on the breadboard from the Pi Hat Protector. Researching the proper ribbon cable direction and orientation, we first figured that our ribbon cable seemed to not match the proper color orientation, so that was why we were not obtaining 3.3V through the GPIO extender. However, after further group discussion, we realized that the GPIO extender may be unable to supply 3.3V, and we instead used the 3.3V port on the Pi Hat Protector to obtain the needed 3.3V for our LED and Rotary encoder.

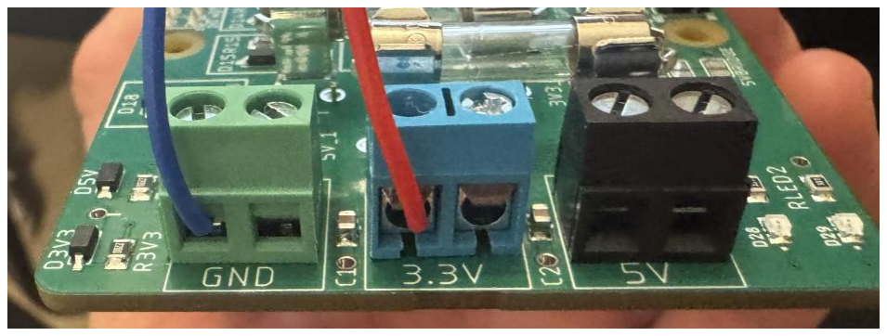
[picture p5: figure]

Figure 3. Shows the GND, 3.3V, 5V to obtain needed voltage since the GPIO extender wouldn’t supply our voltages.

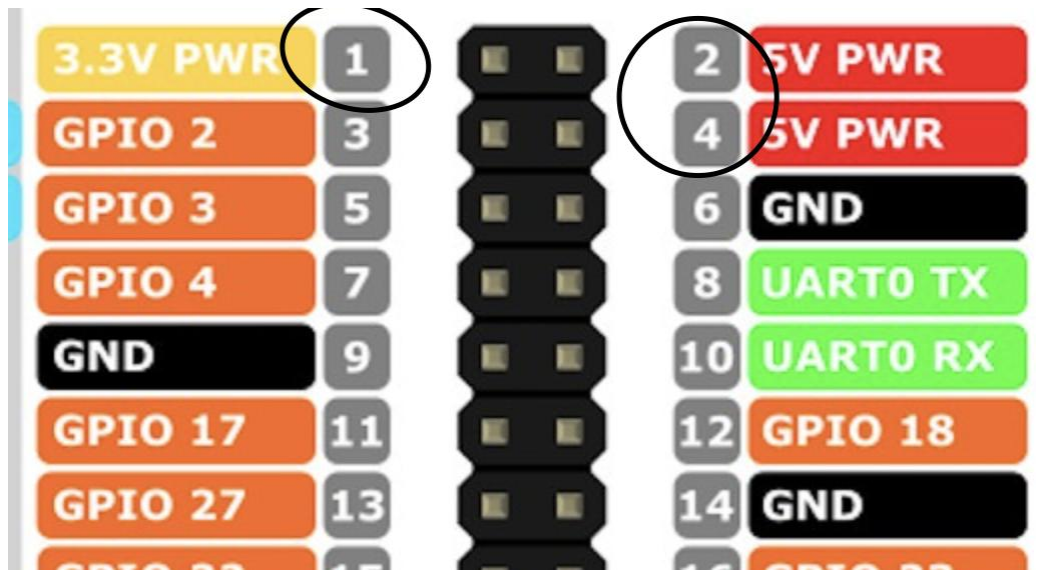
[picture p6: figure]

Figure 4. https://roboticsbackend.com/raspberry-pi-3-pins/ Shows the diagram of the Raspberry Pi Pins- noting the 5V PWR and 3.3V PWR pins.

Using female adapters on these pins can also obtain the needed 3.3V, 5V, GND, and access the GPIO ports.

DigiPot Setup and Rotary Encoder

The MCP4131 digital potentiometer communicates with the Raspberry Pi 4 using SPI (Serial Peripheral Interface). SPI is a synchronous serial protocol where the Raspberry Pi acts as the master and the potentiometer acts as the slave. The master provides the clock (SCK), selects the device using chip select (CS/CE), and sends command/data bytes on MOSI to set the wiper position.

SPI uses four main signal lines: MISO (master in), MOSI (master out), CS/CE (chip select), and SCK (clock). For this project, the important part is sending commands from the Pi to the potentiometer, so MOSI, SCK, and CS/CE are required. MISO is optional unless the program is reading data back.

The following connections between the MCP4131 and the Raspberry Pi 4 were made:

- CS (Chip Select Input; Pin 1) to SPI0 CE0 (GPIO8) (or CE1/GPIO7 if configured that way in code)
- SCK (Serial Clock; Pin 2) to SPI0 SCLK (GPIO11)
- SDI (Serial Data In; Pin 3) to SPI0 MOSI (GPIO10)
- SDO (Serial Data Out; Pin 3, optional) to SPI0 MISO (GPIO9) (only needed if reading back)
- VSS (Pin 4) to Ground
- P0A (Terminal A; Pin 5) to Ground (for our measurement setup)
- VDD (Pin 8) to 3.3V Power

https://www.geeksforgeeks.org/electronics-engineering/what-is-serial-peripheral-interface-spi/

The resistance values of the digital potentiometer are measured with a multimeter device, which connects the two leads of the potentiometer like so:

- P0W (Potentiometer Wiper Terminal; Pin 6 on MCP4131, Pin 9 on MCP4231) to Multimeter COM (Ground)
- P0B (Potentiometer Terminal B; Pin 7 on MCP4131, Pin 10 on MCP4231) to Multimeter Positive Input

The digital potentiometer has a rotary track of resistant material within most of its circumference sandwiches between Terminals A and B, and the wiper serves as a voltage divider to provide an output resistance. The 8th slide of this presentation (https://www.slideshare.net/slideshow/sensors-and-its-classification-1/121507075) shows a top-down view of the device with the roles terminals eminently shown.

Accessing and Using a GPIO
Each of the Raspberry Pi 4 GPIOs are accessible through functions of the Python pigpio library. Because of the OOP architecture of the library, all the library’s functions are methods of the pigpio class and are called via this syntax: pigpio.[function_name()].

Datasheet: https://ww1.microchip.com/downloads/en/DeviceDoc/22060b.pdf

This is a list of its methods used to communicate with the GPIOs alongside their descriptions:

- pigpio.pi() – initializes the pigpio class
- spi_open(SPI_CHANNEL, SPI_SPEED, SPI_FLAGS) – opens the SPI handle (the number referencing the SPI device, the potentiometer), based on the desired SPI channel, speed of the SPI communication (bits per second), and flag settings
- spi_write(HANDLE, BYTES_TO_WRITE) – writes the data bytes provided in a list [] to the handle
- spi_close(HANDLE) – closes the SPI handle
- stop() – stops the Raspberry Pi connection and drops pigpio resources

pigpio library: https://abyz.me.uk/rpi/pigpio/python.html#spi_write

Both the MCP4131 and the MCP4231 are 7-bit digital potentiometers, which means that the range of resistance steps, or increments between Ohm (Ω) values, is [0, 128]. In the Python program potentiometer.py, which uses calls to the pigpio library, the constant MAX_STEPS is set to 128 = 2

7
, offering 129 total steps from 0 to the constant MAX_OHMS value, which is 10,000.

To program the various values of resistance, the Python program opens the SPI handle, the number that represents the potentiometer, using a chosen SPI channel, bits per second, and flags settings. Then, the program attempts to start the cycle to approximate the resistance across Terminal A and the wiper by iterating through the necessary Ohm (Ω) values and the step values in [0, MAX_STEPS] in two modes. Each iteration has some delay measured in seconds.

First, an Ohm value is converted to a byte step value in the range [0, MAX_STEPS]. Before this, however, the program ensures that for all Ohm values, 0 ≤ Ohm value ≤ MAX_OHMS. If the Ohm value is less than 0, then it is reassigned to 0, but if the Ohm value is greater than MAX_OHMS, then it is reassigned to MAX_OHMS. Then, the corresponding step value is found using this formula:

step_value = int((ohm_value / MAX_OHMS) * MAX_STEPS)

Second, the program sets the potentiometer steps by writing the data bytes to the potentiometer’s SPI handle. If the supplied step value is in the range [0, MAX_STEPS], the program writes the command bytes to the potentiometer’s SPI handle and prints the expected approximate resistance to verify with the multimeter. This approximate Ohm value is found by performing the conversion from byte steps to Ohms using the formula. But, if the supplied step value is outside this range, then the program warns the user that the supplied step value is invalid. To reiterate, the first mode of the cycle requires converting Ohms to steps in each iteration, while the second mode does not require converting units.

Software Logic and Library Implementation
We used the Python pigpio library to access GPIO and SPI features on the Raspberry Pi. Before running the program, the pigpio daemon must be active so the script can connect to the Pi’s GPIO resources. In code, the connection is created using pi = pigpio.pi(), then SPI is opened using spi_open(...) and command bytes are sent with spi_write(...).

For inputs (such as the rotary encoder switch or encoder channels), internal pull-up or pull-down resistors are used so the input pin does not float when the switch is open. This prevents random state changes caused by noise and makes the input behavior consistent during testing.

System I/O and GPIO Allocation

To keep the hardware organized and prevent pin conflicts, a GPIO reference was created that lists the Raspberry Pi GPIO names, their functional role in the project, their default power-up state, and the state used during normal operation. Each signal also shows whether a pull-up or pull-down is used, along with the source connection for inputs and the drive destination for outputs. This makes it easier to understand what each pin is doing without tracing wires on the breadboard.

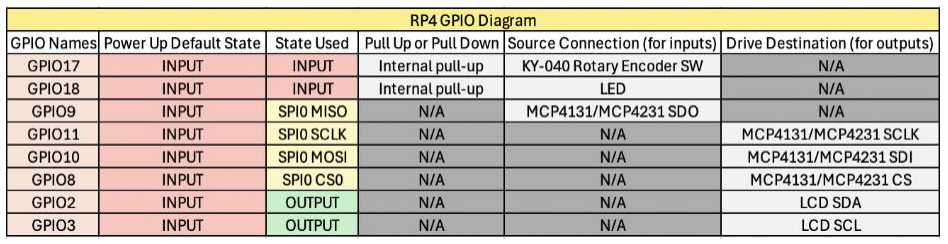
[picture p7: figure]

Figure 5. This figure documents which Raspberry Pi GPIO pins are assigned to each project function and shows signal direction (input into the Pi vs output from the Pi). Including default power-up state and pull configuration helps avoid floating inputs and unexpected behavior during startup. This figure is important because it prevents pin conflicts and speeds up debugging when the system is expanded.

To avoid power mistakes, we also documented how power is distributed across the system. The power reference lists each device that requires power and shows which voltage rail it uses. This makes it easy to confirm correct voltage selection (3.3V vs 5V) and shared ground.

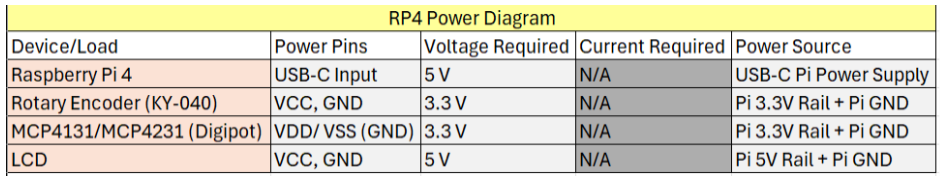
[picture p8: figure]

Figure 6. This figure shows how power is routed to each device and what voltage rail is sued. This is important because using the wrong rail can damage hardware, and missing a shared ground can cause unstable or incorrect readings. Having this documented makes hardware bring-up and troubleshooting much faster.

Power Supply Simulation Check

We simulated a ± 12V DC supply derived from a 24V source to check that both output rails are stable with no load and under load. This let us verify expected beahviro before building it physically.

During testing, we found that a single 240Ω resistor on each rail produced approximately 50 mA, but it exceeded its power rating over time due to power dissipation. To fix that, we used four 60Ω resistors on each rail so the power is spread across multiple ¼W resistors. This keeps the load behavior similar while reducing overheating risk.

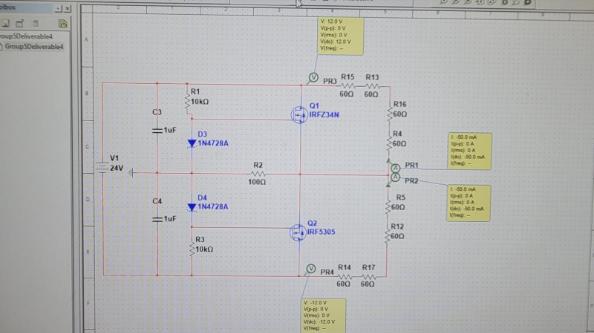
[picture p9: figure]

Figure 7. This figure shows the simulated power supply operation without resistive loading. It verifies that the circuit produces the expected positive and negative reference outputs from the 24V input. This matters because it confirms the supply works in the simplest case before checking performance under load.

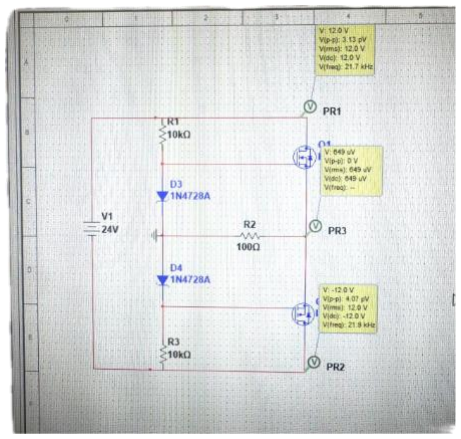
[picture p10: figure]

Figure 8. This figure shows the supply with resistive loads added to simulate current draw and evaluate stability. It is important because it demonstrates whether the output rails stay near ±12V under realistic conditions and helps confirm components are not pushed past safe operating limits.

PCB File Review and “Blank Hat” Starting Point

To prepare for PCB work, we opened the provided Pi Hat Protector (.brd and .sch) files and reviewed the routing needed to map the Raspberry Pi GPIO header. This helped us understand routing constraints and why multiple PCB layers are used. Multiple layers mainly provide routing space and cleaner signal/power paths.

We also reviewed the protection components. Zener diodes are oriented opposite of regular diodes so they can clamp voltage when reverse-biased, helping protect GPIO pins from spikes or incorrect wiring.

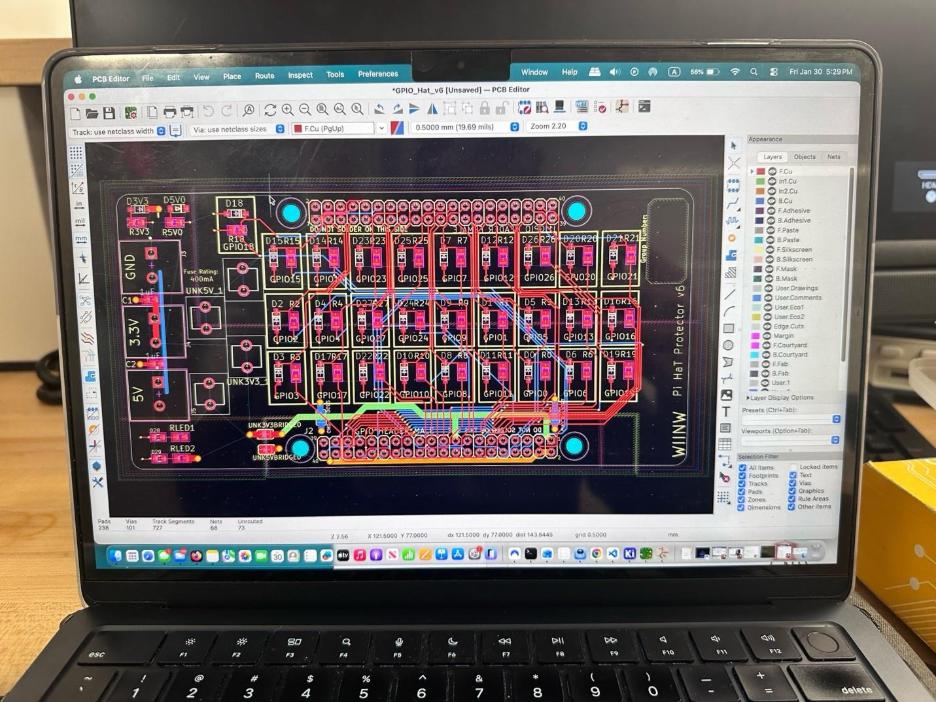
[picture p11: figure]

Figure 9. This figure shows the provided PCB opened in the CAD tool for inspection of routing density, layer usage, and protection components. This is important because it gave us a real reference design to learn from before making our own board, especially around the GPIO header where routing gets crowded.

Next, we saved a simplified “blank” board version by stripping away most routing while keeping the GPIO header (and the general board sturcture). This gives us a clean starting point for our own Pi-HAT design later.

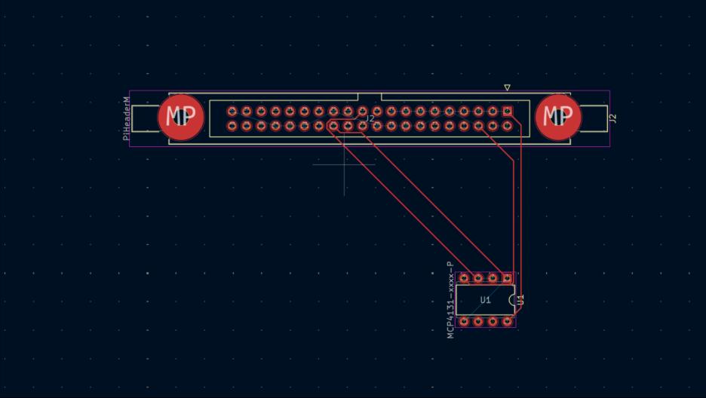
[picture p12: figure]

Figure 10. This figure shows a simplified canvas version of the board with the Raspberry Pi header preserved. This is important because it sets up an organized starting point for future PCB development without the clutter of the original routing, while keeping the physical header constraints we must design around.

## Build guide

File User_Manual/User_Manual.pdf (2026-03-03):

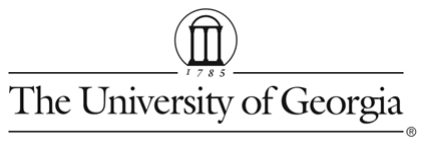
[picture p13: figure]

ECSE 2920: Design Methodology User Manual
Skeleton/Outline Version 2

Group 5

Skeleton Table of Contents

Basics (Features)

Current Deliverable Design

Digital Potentiometer Circuit
For the Digital Potentiometer circuit, the Digital Potentiometer is controlled through a Python script and, through user input. All it does is change the resistance across Terminal A and the Wiper pins. The proper usage would be running the circuit with the Raspberry PI powered on and using a Multimeter to measure the resistance to display that the Digi Pot is working correctly, and the resistance is changing to needed values.

Rotary Encoder Circuit
For the Rotary Encoder Circuit, the physical rotary encoder is pressed, when the PI is on, and the circuit is run, which turns the LED on and off successfully.

Safety Information

Make sure the Raspberry Pi is powered off and/or unplugged before making changes or adjusting the live circuit.
Make sure that a live wire is not touching any metal part of the Pi Hat protector or Raspberry Pi.
Ensure that the device itself is adequately cooled.

List of Components

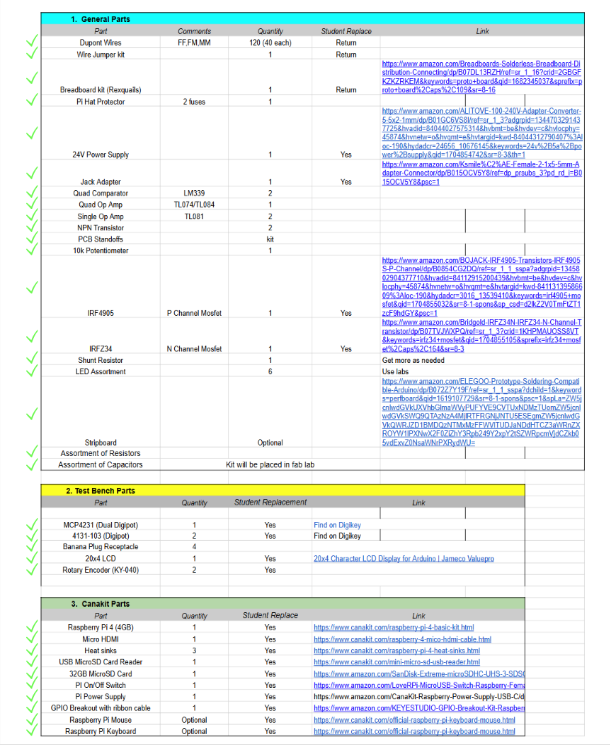
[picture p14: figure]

Connecting the Raspberry Pi 4

Circuit control script should be auto set up to be run at boot/plug in.

Using the Electronics Tool Bench

Digital Potentiometer
…

User Interface

FAQ
N/A

To do rubric for final design:

Write a complete step-by-step document instructing a novice user how to use your project. Think about
your project as a product bought by the user. The manual will instruct the user on all of the functions of
your design. Hint: Drawing on your own experiences of reading (or deciding not to read user manuals)
will help your team create an interesting piece.
- From your own experience recall that, pictures, drawings, diagrams, etc… make a user’s manual
much more beneficial.
- User manuals have several different sections, so don’t forget to think about a section on errors or what might go wrong, faqs, clarification, etc…
- User Manuals also contain safety information for the user.
- Your user manual may also include informative Youtube videos or other informative outlets to aid the user.
- Use your creativity…
o Websites
o Videos
o Your other cool ideas….

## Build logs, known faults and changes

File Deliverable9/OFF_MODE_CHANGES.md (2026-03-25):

# OFF Mode — Implementation Guide

Apply these changes to add a top-level OFF / Mode Select screen to the testbench Driver.

## Overview

- On boot, the system starts in OFF state (all outputs disabled, LCD off)
- A new top-level screen shows two options: **OFF** and **Mode Select**
- **OFF** safely shuts down all outputs (square wave, DC reference) and turns off the LCD (backlight + display)
- **Mode Select** turns the LCD back on and enters the existing Mode Select menu
- From Mode Select, **Back** and **Main** return to this top-level screen
- All other sub-menus are unchanged — their "Main" still goes to Mode Select as before

---

## Change 1: Fix `lcd.backlight()` in `i2c_lcd.py`

The `backlight()` method has the I2C write commented out. Uncomment it so toggling the backlight actually takes effect on hardware.

**Find this** (around line 145):

```python
def backlight(self, on):
    """
    Switch backlight on (True) or off (False).
    """
    self.backlight_on = on
    # Push a harmless write so the state changes on the backpack
    '''try:
        self._byte(0x00, 0x00)
    except Exception:
        pass'''
```

**Replace with:**

```python
def backlight(self, on):
    """
    Switch backlight on (True) or off (False).
    """
    self.backlight_on = on
    # Push a harmless write so the state changes on the backpack
    try:
        self._byte(0x00, 0x00)
    except Exception:
        pass
```

---

## Change 2: Add `ensure_all_off()` and `run_top_screen()` to `Driver.py`

Add these two functions **after** `setup_callbacks(state, pi, lcd)` and **before** `run_function_generator_menu()`.

**Find this:**

```python
setup_callbacks(state, pi, lcd)

def run_function_generator_menu():
```

**Replace with:**

```python
setup_callbacks(state, pi, lcd)

def ensure_all_off():
    """Safely shut down all outputs and turn off the LCD."""
    sq_gen.stop()
    dc_ref.stop()
    state['fg_output_on'] = False
    state['dc_output_on'] = False
    lcd.clear()
    lcd.backlight(False)
    lcd._inst(0x08)  # display off

def run_top_screen():
    """Top-level screen: OFF / Mode Select. Returns when Mode Select is chosen."""
    while True:
        # Turn LCD back on for the menu
        lcd.backlight(True)
        lcd._inst(0x0C)  # display on

        choice = pick_menu("System", ["OFF", "Mode Select"])

        if choice == "OFF":
            ensure_all_off()

        elif choice == "Mode Select":
            return

def run_function_generator_menu():
```

---

## Change 3: Modify the main loop in `Driver.py`

Wrap the existing Mode Select loop inside a `run_top_screen()` call, and call `ensure_all_off()` on boot.

**Find this** (at the bottom of Driver.py):

```python
print("Starting...")
try:
    while True:
        choice = pick_menu(
            "Mode Select",
            ["Function Generator", "Ohmmeter", "Voltmeter", "DC Reference", "Back", "Main"],
        )

        if choice == "Function Generator":
            result = run_function_generator_menu()

        elif choice == "Ohmmeter":
            result = run_ohmmeter()

        elif choice == "Voltmeter":
            result = run_voltmeter_menu()

        elif choice == "DC Reference":
            result = run_dc_reference_menu()

        elif choice in ("Back", "Main"):
            pass
```

**Replace with:**

```python
print("Starting...")
ensure_all_off()
try:
    while True:
        run_top_screen()

        while True:
            choice = pick_menu(
                "Mode Select",
                ["Function Generator", "Ohmmeter", "Voltmeter", "DC Reference", "Back", "Main"],
            )

            if choice == "Function Generator":
                result = run_function_generator_menu()

            elif choice == "Ohmmeter":
                result = run_ohmmeter()

            elif choice == "Voltmeter":
                result = run_voltmeter_menu()

            elif choice == "DC Reference":
                result = run_dc_reference_menu()

            elif choice in ("Back", "Main"):
                break  # go back to top screen
```

---

## Key Details

- `0x08` is the HD44780 instruction for **display off** (turns off the display without losing content)
- `0x0C` is the HD44780 instruction for **display on, cursor off, blink off**
- `lcd.backlight(False)` sets the PCF8574T backlight pin low via I2C
- `ensure_all_off()` is called on boot so the hardware always starts in a known-off state
- The `finally` block at the bottom of Driver.py (cleanup on exit) is **not changed**
- No sub-menu functions are changed — only the top-level flow is modified

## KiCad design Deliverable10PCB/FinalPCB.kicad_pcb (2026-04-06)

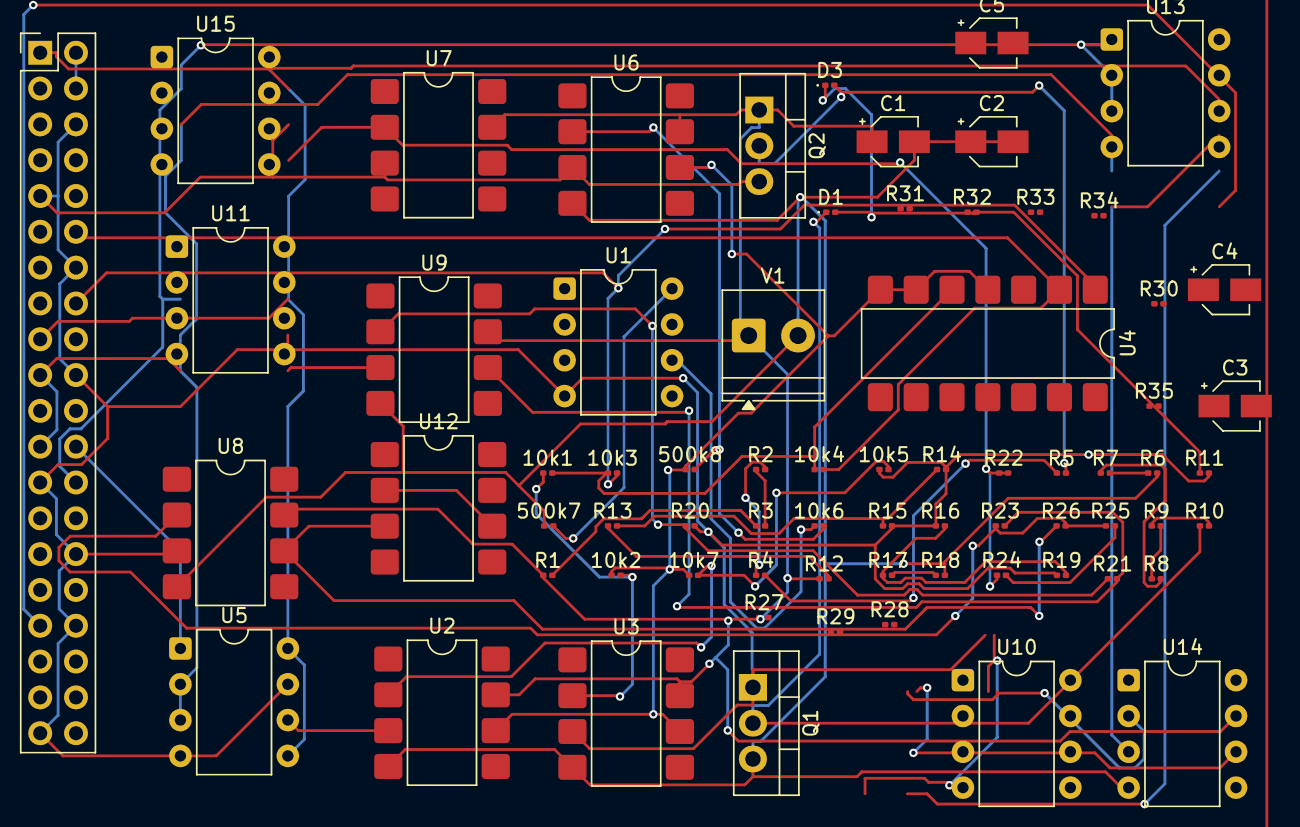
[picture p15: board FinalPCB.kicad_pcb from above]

Board: 2 copper layers, 70 parts (0 on the bottom side), 53 nets.

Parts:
10k1, 10k2, 10k3, 10k4, 10k5, 10k6, 10k7, 500k7: R; R_0201_0603Metric
500k8: R_Measure; R_0201_0603Metric
C1, C2: 0.0000001; CP_Elec_3x5.3
C3: 470uF; CP_Elec_3x5.3
C4, C5: 10nf; CP_Elec_3x5.3
D1, D3: D; D_0201_0603Metric
J2: PiHeaderM; PinHeader_2x20_P2.54mm_Vertical
Q1: NMOS; TO-220-3_Vertical
Q2: PMOS; TO-220-3_Vertical
R1, R2, R3, R4, R5, R6, R7, R8, R9, R10, R11, R12, R13, R14, R15, R16, R17, R18, R19: 100; R_0201_0603Metric
R20, R22, R23, R25, R26, R28: 10k; R_0201_0603Metric
R21: 20k; R_0201_0603Metric
R24: 30k; R_0201_0603Metric
R27, R31, R32, R33, R34: 100k; R_0201_0603Metric
R29: 70k; R_0201_0603Metric
R30, R35: 220k; R_0201_0603Metric
U1, U5, U13: MCP4131-xxxx-P; DIP-8_W7.62mm
U2, U3, U6, U7, U8, U9, U12: LM741; SMDIP-8_W7.62mm
U4: LM339; SMDIP-14_W7.62mm
U10, U11, U14: TL081; DIP-8_W7.62mm
U15: MCP4231-103E_P; DIP-8_W7.62mm
V1: 24; TerminalBlock_Phoenix_PT-1,5-2-3.5-H_1x02_P3.50mm_Horizontal

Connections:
+3.3V: 10k1.2, U4.5 (+)
+12V: C1.1, Q2.1 (D), R1.1, R12.1, U2.7 (V+), U3.7 (V+), U6.7 (V+), U7.7 (V+), U8.7 (V+), U9.7 (V+), U10.7 (V+), U11.7 (V+), U14.7 (V+), V1.1
-12V: 500k7.1, C1.2, C2.1, C2.2, Q1.3 (S), R6.2, R18.2, U2.4 (V-), U3.4 (V-), U6.4 (V-), U8.4 (V-), U9.4 (V-), U10.4 (V-), U11.4 (V-), U14.4 (V-), V1.2
/3.3V: 10k3.1, 10k4.1, J2.1, J2.17, U13.5 (P0A), U13.8 (V_{DD}), U15.7 (P1A), U15.8 (P0A)
/5V: J2.2, J2.4
/CE0: J2.24, U13.1 (~CS), U15.1 (~CS)
/CE1: J2.26, U1.1 (~CS), U5.1 (~CS)
/GND*GPIO: J2.6, J2.9, J2.14, J2.20, J2.25, J2.30, J2.34, J2.39
/GPIO10*: J2.19, U1.3 (SDI/SDO), U5.3 (SDI/SDO), U13.3 (SDI/SDO), U15.3 (SDI)
/GPIO11*: J2.23, U1.2 (SCK), U5.2 (SCK), U13.2 (SCK), U15.2 (SCK)
/GPIO13*: C3.2, J2.33, U13.6 (P0W)
GND: 10k5.1, Q1.1 (D), Q2.3 (S), R11.2, R14.2, R15.2, R16.1, R19.1, R20.2, R27.1, R31.2, R34.2, U1.4 (V_{SS}), U3.3 (+), U5.7 (P0B), U6.3 (+), U7.3 (+), U8.3 (+), U13.4 (V_{SS}), U13.7 (P0B), U14.3 (+), U15.4 (VSS), U15.5 (P1B)
unnamed: 10k3.2, U4.1
unnamed: 10k4.2, U4.2
unnamed: C3.1, R27.2, R28.1
unnamed: C4.1, R30.2, R33.2, U10.6
unnamed: C5.1, R35.2, U11.6
unnamed: D1.2 (A), D3.1 (K), R11.1
unnamed: D1.1 (K), Q1.2 (G), R10.1
unnamed: D3.2 (A), Q2.2 (G), R5.2
unnamed: R1.2, R3.1
unnamed: R2.1, R3.2
unnamed: R2.2, R4.1
unnamed: R4.2, R5.1
unnamed: R6.1, R7.2
unnamed: R7.1, R8.2
unnamed: R8.1, R9.2
unnamed: R9.1, R10.2
unnamed: R12.2, R13.1
unnamed: R13.2, R14.1, R15.1
unnamed: R16.2, R17.1, R19.2
unnamed: R17.2, R18.1
unnamed: R21.2, R23.2, U9.6
unnamed: R24.2, R25.2
unnamed: R29.2, R32.2, U14.6
unnamed: 10k6.1, U1.6 (P0W)
unnamed: 500k7.2, U1.8 (V_{DD})
unnamed: U2.3 (+), U5.6 (P0W)
unnamed: 10k5.2, 10k7.2, U2.2 (-)
unnamed: 10k1.1, 10k2.2, U3.2 (-)
unnamed: 10k2.1, 10k7.1, 500k8.1, U2.6, U3.6, U4.4 (-), U4.6 (-), U4.7 (+), U6.6
unnamed: U5.5 (P0A), U5.8 (V_{DD})
unnamed: 10k6.2, 500k8.2, U6.2 (-)
unnamed: R23.1, R25.1, R26.2, U8.2 (-)
unnamed: R20.1, R21.1, U9.2 (-)
unnamed: R31.1, U10.3 (+)
unnamed: C4.2, R30.1, R32.1, U10.2 (-)
unnamed: R34.1, U11.3 (+)
unnamed: C5.2, R33.1, R35.1, U11.2 (-)
unnamed: R26.1, U8.6, U12.3 (+)
unnamed: U12.2 (-), U12.6
unnamed: R28.2, R29.1, U14.2 (-)
unnamed: R22.1, R22.2, R24.1, U7.2 (-), U15.6 (P1W)

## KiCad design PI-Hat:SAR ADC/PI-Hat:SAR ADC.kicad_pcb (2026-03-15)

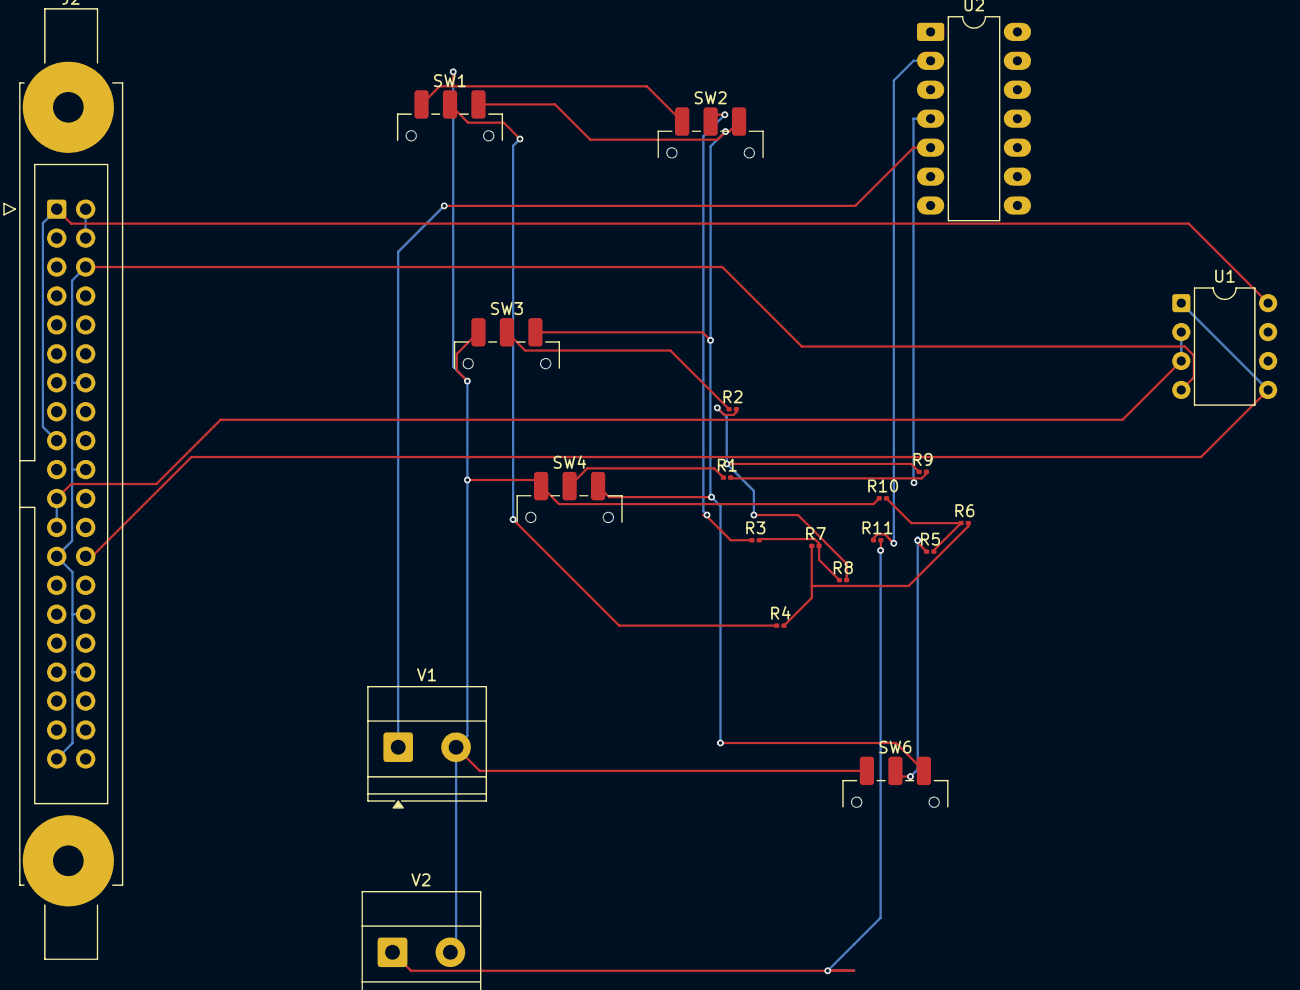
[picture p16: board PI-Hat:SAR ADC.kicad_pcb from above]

Board: 2 copper layers, 21 parts (0 on the bottom side), 20 nets.

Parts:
J2: PiHeaderM; IDC-Header_2x20-1MP_P2.54mm_Latch6.5mm_Vertical
R1, R2, R3, R4, R5, R10: 200; R_0201_0603Metric
R6, R7, R8, R9: 100; R_0201_0603Metric
R11: 10k; R_0201_0603Metric
SW1: Key = 2; SW_SPDT_CK_JS102011SAQN
SW2: Key = 3; SW_SPDT_CK_JS102011SAQN
SW3: Key = 4; SW_SPDT_CK_JS102011SAQN
SW4: Key = 5; SW_SPDT_CK_JS102011SAQN
SW6: Key = 1; SW_SPDT_CK_JS102011SAQN
U1: MCP4131-xxxx-P; DIP-8_W7.62mm
U2: LM339; DIP-14_W7.62mm_LongPads
V1: 1; TerminalBlock_Phoenix_MKDS-1,5-2-5.08_1x02_P5.08mm_Horizont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
V2: 1.7; TerminalBlock_Phoenix_MKDS-1,5-2-5.08_1x02_P5.08mm_Horizont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

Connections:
+5V: SW1.3 (C), SW2.3 (C), SW3.3 (C), SW4.3 (C), SW6.3 (C)
/3V3GPIO*: J2.1, J2.17, U1.8 (V_{DD})
/5VGPIO*: J2.2, J2.4
/GND*GPIO: J2.6, J2.14, J2.20, J2.25, J2.30, J2.34, J2.39, U1.4 (V_{SS})
/GPIO7*: J2.26, U1.1 (~CS), U1.5 (P0A)
/GPIO11*: J2.21, J2.23, U1.2 (SCK), U1.3 (SDI/SDO)
GND: R10.1, SW1.1 (A), SW2.1 (A), SW3.1 (A), SW4.1 (A), SW6.1 (A), V1.2, V2.2
unnamed: R2.2, R8.2, R9.1
unnamed: R3.2, R7.2, R8.1
unnamed: R4.2, R6.2, R7.1
unnamed: R5.2, R6.1, R10.2
unnamed: R11.1, U2.2
unnamed: R11.2, V2.1
unnamed: R4.1, SW1.2 (B)
unnamed: R3.1, SW2.2 (B)
unnamed: R2.1, SW3.2 (B)
unnamed: R1.1, SW4.2 (B)
unnamed: R5.1, SW6.2 (B)
unnamed: U2.5 (+), V1.1
unnamed: R1.2, R9.2, U2.4 (-)

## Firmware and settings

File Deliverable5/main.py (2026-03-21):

"""
main.py – Entry point for the digital potentiometer controller.

Initialises hardware (pigpio, I2C LCD, SPI for the MCP4231), then runs a
page-based menu loop driven by a rotary encoder and its push-button:

  1. Main page       – choose Pot 1 or Pot 2
  2. Var/Const page  – choose Variable or Constant resistance mode
  3a. Variable page  – dial in a resistance with the encoder, press to set
  3b. Constant page  – pick a preset (100, 1k, 5k, 10k), press to set

A long button hold (2-3 s) on pages 3a/3b returns to the main page.
"""

import pigpio
import time
import i2c_lcd
from ohms_steps import (
    ohms_to_step, step_to_ohms,
DEFAULT_OHMS, SPI_CHANNEL, SPI_SPEED, SPI_FLAGS,
    CONSTANT_LABELS,
)
from callbacks import (
    setup_callbacks, clear_callbacks,
    menu_direction_callback, menu_button_callback,
    varconst_direction_callback, varconst_button_callback,
    pot_direction_callback, callback_set_digi,
    constant_direction_callback, constant_button_callback,
    PIN_A, PIN_B,
)
import rotary_encoder

# ── Hardware setup ──────────────────────────────────────

# GPIO pin for the rotary encoder's built-in push-button 
rotaryEncoder_pin = 17

# Connect to the pigpio daemon 
pi = pigpio.pi()
if not pi.connected:
    exit()

# Initialise the 20x4 I2C LCD (PCF8574T backpack, default address 0x27)
lcd = i2c_lcd.lcd(pi, width=20)

# Open SPI for the MCP4231 dual digital potentiometer
spi_handle = pi.spi_open(SPI_CHANNEL, SPI_SPEED, SPI_FLAGS)
print(f"SPI handle: {spi_handle}")

# Shared state dictionary
# Passed to callbacks.py so interrupt handlers can read/write program state.
state = {
    'ohms': DEFAULT_OHMS,                        # current target resistance (variable mode)
    'selected_pot': 0,                           # 0 = Pot 1, 1 = Pot 2
    'pot_values': [DEFAULT_OHMS, DEFAULT_OHMS],  # [Pot 1 Value, Pot 2 Value]
    'menu_selection': 0,                         # highlighted item on the main page
    'isMainPage': True,                          # flag: currently on main page?
    'isVarConstPage': False,                     # flag: currently on var/const page?
    'var_const_selection': 0,                    # 0 = Variable, 1 = Constant
    'constant_selection': 0,                     # index into CONSTANT_OHMS presets
    'last_time': None,                           # timestamp of last encoder detent (speed calc)
    'button_press_tick': None,                   # tick when button was pressed (hold detection)
    'button_last_tick': None,                    # tick of last accepted press (debounce)
    'spi_handle': spi_handle,                    # pigpio SPI handle for MCP4231
    'active_callbacks': [],                      # list of pigpio callbacks to cancel on page change
}


# Encoder A/B channels
pi.set_mode(PIN_A, pigpio.INPUT)
pi.set_mode(PIN_B, pigpio.INPUT)
pi.set_pull_up_down(PIN_A, pigpio.PUD_UP)
pi.set_pull_up_down(PIN_B, pigpio.PUD_UP)

# Encoder button 
pi.set_mode(rotaryEncoder_pin, pigpio.INPUT)
pi.set_pull_up_down(rotaryEncoder_pin, pigpio.PUD_UP)

# 10 ms glitch filter on the button pin only.
# The encoder channels are debounced by the Gray-code state machine in
# rotary_encoder.decoder, so they don't need a glitch filter.
pi.set_glitch_filter(rotaryEncoder_pin, 10000)

# Inject hardware references into the callbacks module
setup_callbacks(state, pi, lcd)

# Flag for if powered on for the first time for saving pot_1 and pot_2 values
isPowerOnFirstTime = True

print("Starting...")
try:
    while True:
        # main page
        state['isMainPage'] = True
        state['menu_selection'] = 0
        state['button_last_tick'] = None
        clear_callbacks(state)

        # Draw the initial menu screen
        lcd.put_line(0, 'Select a Pot:')
        lcd.put_line(1, '> Pot 1')
        lcd.put_line(2, '  Pot 2')
        lcd.put_line(3, '')

        # Register encoder rotation + button press callbacks
        decoder = rotary_encoder.decoder(pi, PIN_A, PIN_B, menu_direction_callback)
        #print("decoder", decoder)
        cb_btn = pi.callback(
            rotaryEncoder_pin, pigpio.FALLING_EDGE, menu_button_callback)
        #print("cb_btn", cb_btn)
        state['active_callbacks'] = [decoder, cb_btn]

        # Spin until the button callback clears isMainPage
        while state['isMainPage']:
            time.sleep(0.05)

        # page 2
        state['isVarConstPage'] = True
        state['var_const_selection'] = 0
        state['button_last_tick'] = None
        clear_callbacks(state)

        lcd.put_line(0, 'Resistance Type:')
        lcd.put_line(1, '> Variable')
        lcd.put_line(2, '  Constant')
        lcd.put_line(3, '')

        decoder = rotary_encoder.decoder(pi, PIN_A, PIN_B, varconst_direction_callback)
        cb_btn = pi.callback(
            rotaryEncoder_pin, pigpio.FALLING_EDGE, varconst_button_callback)
        state['active_callbacks'] = [decoder, cb_btn]

        while state['isVarConstPage']:
            time.sleep(0.05)

        if state['var_const_selection'] == 0:
            #print("var_const_selection selected_pot: ", state['selected_pot'])
            #page 3a
            state['isMainPage'] = False
            state['last_time'] = None
            state['button_last_tick'] = None
            clear_callbacks(state)
            
            # Reset to default and display starting value
            #if (isPowerOnFirstTime == True):
            #    state['ohms'] = DEFAULT_OHMS
            #    isPowerOnFirstTime = False
            #else:
            #    state['ohms'] = state['pot_values'][state['selected_pot']]
            # Save the new ohm value of the selected pot
            state['ohms'] = state['pot_values'][state['selected_pot']]
                
            step = ohms_to_step(state['ohms'])
            lcd.put_line(0, f'Pot {state["selected_pot"] + 1}')
            #lcd.put_line(1, f'Ohms: {step_to_ohms(step):.1f}')
            lcd.put_line(1, f'Ohms: {5000}')
            lcd.put_line(2, '')
            lcd.put_line(3, '')

            # Encoder rotation adjusts ohms; button press writes to MCP4231.
            # EITHER_EDGE on button so we can detect long holds on release.
            decoder = rotary_encoder.decoder(pi, PIN_A, PIN_B, pot_direction_callback)
            cb_btn = pi.callback(
                rotaryEncoder_pin, pigpio.EITHER_EDGE, callback_set_digi)
            state['active_callbacks'] = [decoder, cb_btn]

            # Stay until a long hold sets isMainPage = True
            while not state['isMainPage']:
                #print("while not state ismainpage selected_pot: ", state['selected_pot'])
                '''if state['button_press_tick'] is not None:
                    now = pi.get_current_tick()
                    if pigpio.tickDiff(state['button_press_tick'], now) >= 2_000_000:
                        # 3 seconds elapsed while held 
                        #state['ohms'] = DEFAULT_OHMS

                        # Reset to default and display starting value
                        #if (isPowerOnFirstTime == False):
                        #    state['ohms'] = state['pot_values'][state['selected_pot']]
                        #else:
                        #    state['ohms'] = DEFAULT_OHMS
                        #    isPowerOnFirstTime = False
                        # Save the new ohm value of the selected pot
                        state['ohms'] = state['pot_values'][state['selected_pot']]
                            
                        state['button_press_tick'] = None
                        state['isMainPage'] = True'''
                time.sleep(0.05)

        else:
            # page 3b
            state['isMainPage'] = False
            state['constant_selection'] = 0
            state['button_last_tick'] = None
            clear_callbacks(state)

            lcd.put_line(0, f'Pot {state["selected_pot"] + 1} - Constant')
            lcd.put_line(1, f'Value: {CONSTANT_LABELS[0]} Ohms')
            lcd.put_line(2, '')
            lcd.put_line(3, '')

            # Encoder cycles through presets; button writes chosen value.
            decoder = rotary_encoder.decoder(pi, PIN_A, PIN_B, constant_direction_callback)
            cb_btn = pi.callback(
                rotaryEncoder_pin, pigpio.EITHER_EDGE, constant_button_callback)
            state['active_callbacks'] = [decoder, cb_btn]

            while not state['isMainPage']:
                time.sleep(0.05)

except KeyboardInterrupt:
    print("\nStopping...")
    clear_callbacks(state)
    lcd.close()
    pi.spi_close(spi_handle)
    pi.stop()

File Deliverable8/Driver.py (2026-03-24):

"""
Driver.py  –  Function Generator LCD UI
========================================
LCD + rotary-encoder UI for the SquareWaveGenerator and DCReferenceGenerator.
"""

import pigpio
import time

import i2c_lcd
import rotary_encoder
from square_wave import (
    SquareWaveGenerator,
    MIN_FREQ, MAX_FREQ, FREQ_STEP, MAX_AMP, AMP_STEP,
)
from dc_reference import DCReferenceGenerator
from sar_logic import SAR_ADC

PIN_A = 22
PIN_B = 27
ROTARY_BTN_PIN = 17

DEBOUNCE_US = 200_000
HOLD_US = 2_000_000

AMP_STEP_UI = AMP_STEP  # 0.3125 V per step, imported from square_wave

MIN_DC_VOLT = -5.0
MAX_DC_VOLT = 5.0
DC_VOLT_STEP = 0.625
DC_SPI_CHANNEL = 0
DC_SPI_SPEED = 50_000
DC_SPI_FLAGS = 0

COMPARATOR_PIN = 24
VREF = 5.0
VM_SPI_CHANNEL = 1
VM_SPI_SPEED = 50_000
VM_SPI_FLAGS = 0

pi = pigpio.pi()
if not pi.connected:
    raise SystemExit("Cannot connect to pigpio daemon. Run 'sudo pigpiod' first.")

lcd = i2c_lcd.lcd(pi, width=20)

spi_dc = pi.spi_open(DC_SPI_CHANNEL, DC_SPI_SPEED, DC_SPI_FLAGS)
print(f"[DEBUG] spi_dc handle = {spi_dc}")
if spi_dc < 0:
    raise SystemExit(f"spi_open failed with error {spi_dc}")

gen = SquareWaveGenerator(pi, spi_dc, debug=True)
gen.set_frequency(1000)

dc_ref = DCReferenceGenerator(pi, spi_dc, debug=True)

spi_vm = pi.spi_open(VM_SPI_CHANNEL, VM_SPI_SPEED, VM_SPI_FLAGS)
voltmeter = SAR_ADC(pi, spi_vm, COMPARATOR_PIN)

for pin in (PIN_A, PIN_B):
    pi.set_mode(pin, pigpio.INPUT)
    pi.set_pull_up_down(pin, pigpio.PUD_UP)

pi.set_mode(ROTARY_BTN_PIN, pigpio.INPUT)
pi.set_pull_up_down(ROTARY_BTN_PIN, pigpio.PUD_UP)
pi.set_glitch_filter(ROTARY_BTN_PIN, 10_000)

state = {
    'wave_type': 'Square',
    'frequency': 1000,
    'amplitude': 0.0,
    'output_on': False,
    'dc_voltage': 0.0,
    'dc_output_on': False,
    'active_callbacks': [],
    'button_last_tick': None,
    'button_press_tick': None,
    'button_pressed': False,
    'button_held': False,
    'encoder_delta': 0,
}


def clear_callbacks():
    for cb in state['active_callbacks']:
        cb.cancel()
    state['active_callbacks'] = []


def _button_cb(gpio, level, tick):
    if level == 0:
        last = state['button_last_tick']
        if last is not None and pigpio.tickDiff(last, tick) < DEBOUNCE_US:
            return
        state['button_last_tick'] = tick
        state['button_press_tick'] = tick

    elif level == 1:
        press_tick = state['button_press_tick']
        if press_tick is not None:
            if pigpio.tickDiff(press_tick, tick) >= HOLD_US:
                state['button_held'] = True
            else:
                state['button_pressed'] = True
            state['button_press_tick'] = None


def _encoder_cb(direction):
    state['encoder_delta'] += direction


def _attach_callbacks():
    decoder = rotary_encoder.decoder(pi, PIN_A, PIN_B, _encoder_cb)
    cb_btn = pi.callback(ROTARY_BTN_PIN, pigpio.EITHER_EDGE, _button_cb)
    state['active_callbacks'] = [decoder, cb_btn]


def _reset_input():
    state['button_pressed'] = False
    state['button_held'] = False
    state['encoder_delta'] = 0


def _ensure_modes_do_not_conflict(prefer):
    """
    Only one owner should actively drive the shared MCP4231 at a time.
    """
    if prefer == 'square' and state['dc_output_on']:
        dc_ref.stop(clear_to_zero=False)
        state['dc_output_on'] = False
        print("[Driver] DC reference paused because square wave output was enabled")

    elif prefer == 'dc' and state['output_on']:
        gen.stop(clear_wipers=False)
        state['output_on'] = False
        print("[Driver] Square wave paused because DC reference was enabled")


def pick_menu(title, options):
    idx = 0
    _reset_input()

    def _redraw():
        window = max(0, min(idx - 1, len(options) - 3))
        lcd.put_line(0, title[:20])
        for row in range(3):
            i = window + row
            if i < len(options):
                prefix = '>' if i == idx else ' '
                lcd.put_line(row + 1, f"{prefix} {options[i]}"[:20])
            else:
                lcd.put_line(row + 1, '')

    _redraw()
    _attach_callbacks()

    while True:
        if state['encoder_delta'] != 0:
            idx = (idx + state['encoder_delta']) % len(options)
            state['encoder_delta'] = 0
            _redraw()

        if state['button_pressed']:
            state['button_pressed'] = False
            clear_callbacks()
            return options[idx]

        if state['button_held']:
            state['button_held'] = False
            clear_callbacks()
            return 'Back'

        time.sleep(0.02)


def adjust_value(title, value, min_val, max_val, step, fmt):
    _reset_input()

    def _redraw():
        lcd.put_line(0, title[:20])
        lcd.put_line(1, fmt(value)[:20])
        lcd.put_line(2, 'Turn to adjust'[:20])
        lcd.put_line(3, 'Btn:OK  Hold:cancel')

    _redraw()
    _attach_callbacks()

    while True:
        if state['encoder_delta'] != 0:
            value += state['encoder_delta'] * step
            value = max(min_val, min(max_val, value))
            value = round(round(value / step) * step, 10)
            state['encoder_delta'] = 0
            _redraw()

        if state['button_pressed']:
            state['button_pressed'] = False
            clear_callbacks()
            return value

        if state['button_held']:
            state['button_held'] = False
            clear_callbacks()
            return None

        time.sleep(0.02)


def run_type_menu():
    while True:
        choice = pick_menu(f"TYPE: {state['wave_type']}", ['Square', 'Back'])
        if choice == 'Square':
            state['wave_type'] = 'Square'
            lcd.put_line(0, 'Type set: Square')
            lcd.put_line(1, '')
            lcd.put_line(2, '')
            lcd.put_line(3, '')
            time.sleep(0.8)
            return
        elif choice == 'Back':
            return


def run_frequency_menu():
    while True:
        choice = pick_menu(
            f"FREQ: {state['frequency']}Hz",
            ['Adjust', 'Back'],
        )
        if choice == 'Adjust':
            new_val = adjust_value(
                'FREQUENCY',
                float(state['frequency']),
                MIN_FREQ, MAX_FREQ, FREQ_STEP,
                lambda v: f"{int(v)} Hz",
            )
            if new_val is not None:
                state['frequency'] = int(new_val)
                gen.set_frequency(state['frequency'])
        elif choice == 'Back':
            return
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

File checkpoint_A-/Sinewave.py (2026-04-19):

import math
import pigpio

PWM_GPIO = 26

MIN_FREQ = 1000
MAX_FREQ = 10_000
FREQ_STEP = 500

MAX_AMP = 10.0
AMP_STEP = 0.625

SPI_CHANNEL = 0
SPI_BAUD = 1_000_000

CMD_WRITE_WIPER0 = 0x00
MAX_WIPER_STEP = 127


def _clamp(value, lo, hi):
    return max(lo, min(hi, value))


def _interp(x, xp, fp):
    # Bounds check
    if x <= xp[0]:
        return fp[0]
    if x >= xp[-1]:
        return fp[-1]

    # Linear interpolation
    for i in range(1, len(xp)):
        if x <= xp[i]:
            x0, x1 = xp[i - 1], xp[i]
            y0, y1 = fp[i - 1], fp[i]
            if x1 == x0:
                return y0
            frac = (x - x0) / (x1 - x0)
            return y0 + frac * (y1 - y0)

    # Fail safe
    return fp[-1]


# desired amplitude -> corrected command amplitude
CAL_TABLES = {
    1000: {
        0.625: 0.355,
        1.250: 0.733,
        2.500: 1.563,
        5.000: 3.289,
        7.500: 4.891,
        10.000: 7.143,
    },
    2500: {
        0.625: 0.275,
        1.250: 0.581,
        2.500: 1.330,
        5.000: 2.778,
        7.500: 4.046,
        10.000: 6.410,
    },
    5000: {
        0.625: 0.349,
        1.250: 0.710,
        2.500: 1.563,
        5.000: 3.125,
        7.500: 4.808,
        10.000: 6.944,
    },
    7500: {
        0.625: 0.407,
        1.250: 0.919,
        2.500: 1.953,
        5.000: 4.032,
        7.500: 6.048,
        10.000: 8.333,
    },
    10000: {
        0.625: 0.528,
        1.250: 1.250,
        2.500: 2.778,
        5.000: 5.556,
        7.500: 8.523,
        10.000: 10.000,
    },
}


class SineWaveGenerator:
    def __init__(self, pi, debug=False):
        self._pi = pi
        self._frequency = MIN_FREQ
        self._amp_v = 0.0
        self._running = False
        self._wave_id = None
        self._debug = debug

        self._spi = pi.spi_open(SPI_CHANNEL, SPI_BAUD, 0)

        pi.set_mode(PWM_GPIO, pigpio.OUTPUT)
        pi.write(PWM_GPIO, 0)

    def _get_samples(self):
        f = self._frequency
        if f <= 1500:
            return 48
        if f <= 3000:
            return 32
        if f <= 6000:
            return 16
        return 8

    def _write_wiper0(self, step):
        step = int(_clamp(step, 0, MAX_WIPER_STEP))
        self._pi.spi_write(self._spi, bytes([CMD_WRITE_WIPER0, step]))

        if self._debug:
            print(f"[Digipot] Wiper 0 -> step {step}")

    def _snap_amplitude(self, amp):
        snapped = round(float(amp) / AMP_STEP) * AMP_STEP
        return _clamp(round(snapped, 3), 0.0, MAX_AMP)

    def _exp_correction(self):
        """
        Exponential frequency correction.
        Keeps the smooth frequency trend correction in place.
        """
        f = float(self._frequency)
        corr = 0.4065 * ((f / 1000.0) ** 0.312)
        return _clamp(corr, 0.30, 1.00)

    def _find_bracketing_freqs(self, freq):
        freqs = sorted(CAL_TABLES.keys())

        if freq <= freqs[0]:
            return freqs[0], freqs[0]
        if freq >= freqs[-1]:
            return freqs[-1], freqs[-1]

        for i in range(1, len(freqs)):
            if freq <= freqs[i]:
                return freqs[i - 1], freqs[i]

        return freqs[-1], freqs[-1]

    def _table_correction(self, amp):
        """Returns the calibrated amplitude value based on the
           set frequency using CAL_TABLES to do linear
           interpolation."""
        # Find the left-bound and right-bound freqs of the set freq 
        f0, f1 = self._find_bracketing_freqs(self._frequency)

        def corr_at_freq(freq):
            table = CAL_TABLES[freq]
            xs = sorted(table.keys())
            ys = [table[x] for x in xs]
            return _interp(amp, xs, ys)

        """ Use amp to find adjusted amp values for left-bound and
            right-bound freqs. """
        c0 = corr_at_freq(f0)
        c1 = corr_at_freq(f1)

        if f0 == f1:
            return c0

        frac = (self._frequency - f0) / (f1 - f0)
        return c0 + frac * (c1 - c0)

    def _amp_to_step(self, amp):
        amp = self._snap_amplitude(amp)

        exp_corr = self._exp_correction()
        table_corr = self._table_correction(amp)

        corrected_amp = table_corr * exp_corr
        corrected_amp = _clamp(corrected_amp, 0.0, MAX_AMP)

        if self._debug:
            print(
                f"[Cal] freq={self._frequency}Hz "
                f"target={amp:.3f}Vpp "
                f"exp={exp_corr:.3f} "
                f"table={table_corr:.3f} "
                f"final={corrected_amp:.3f}"
            )

        step = round((corrected_amp / MAX_AMP) * MAX_WIPER_STEP)
        return int(_clamp(step, 0, MAX_WIPER_STEP))

    def _build_wave(self):
        """ Outputs the sine wave from the PWM GPIO pin using samples
            in slot_list to switch the pin on/off based on duty cycle. """
        n = self._get_samples()
        lut = [math.sin(2 * math.pi * i / n) for i in range(n)]

        period_us = 1_000_000.0 / self._frequency

        slot_list = [] # contains the samples for storing time
        acc = 0.0 # the ideal time elapsed in a period
        used = 0 # the actual time used per sample

        # Fill the slot list with approx pieces of the ideal period
        for _ in range(n):
            acc += period_us / n
            slot = int(round(acc - used))
            if slot < 1:
                slot = 1
            slot_list.append(slot)
            used += slot

        # The resulting slot list has an error compared to acc
        target_total = int(round(period_us))
        error = target_total - sum(slot_list)
        slot_list[-1] += error

        # If needed, fix the final slot time from 0 to 1
        if slot_list[-1] < 1:
            slot_list[-1] = 1

        # Bit masks for turning the PWM GPIO on and off
        on_mask = 1 << PWM_GPIO
        off_mask = 1 << PWM_GPIO
        # Stores the pulses in a list
        pulses = []

        # Find the duty cycle 
        for sample, slot_us in zip(lut, slot_list):
            # The duty cycle from a lut sample between 0 and 1
            duty = _clamp(0.5 + 0.5 * sample, 0.0, 1.0)

            # high and low pulses comprise the sample value
            high_us = int(round(duty * slot_us))
            low_us = slot_us - high_us

            # high_us > 0 turns on the GPIO, low_us > 0 turns off the GPIO
            if high_us > 0:
                pulses.append(pigpio.pulse(on_mask, 0, high_us))
            if low_us > 0:
                pulses.append(pigpio.pulse(0, off_mask, low_us))

        self._pi.wave_tx_stop()

        if self._wave_id is not None:
            try:
                self._pi.wave_delete(self._wave_id)
            except pigpio.error:
                pass
            self._wave_id = None

        self._pi.wave_clear()
        self._pi.wave_add_generic(pulses)
        wave_id = self._pi.wave_create()
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

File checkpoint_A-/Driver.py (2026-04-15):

"""
Driver.py

Integrated LCD UI driver matching the UI tree from UI.md.

Integrates:
- square_wave.py          (SquareWaveGenerator on CE0)
- dc_reference_single.py  (DCReferenceSingleGenerator on CE0)
- voltmeter.py            (SAR voltmeter on CE1)
- ohmmeter.py             (SAR ohmmeter on CE1)
- callbacks.py            (pick_menu, adjust_value, wait_for_back)
- i2c_lcd.py
- rotary_encoder.py
"""

import time
import pigpio

import i2c_lcd
import rotary_encoder

from callbacks import (
    PIN_A,
    PIN_B,
    ROTARY_BTN_PIN,
    setup_callbacks,
    clear_callbacks,
    pick_menu,
    adjust_value,
    wait_for_back,
)

from square_wave import SquareWaveGenerator, MIN_FREQ, MAX_FREQ, MAX_AMP, AMP_STEP, FREQ_STEP
from dc_reference_single import DCReferenceSingleGenerator, MIN_VOLT, MAX_VOLT

from voltmeter import (
    COMPARATOR1_PIN,
    run_measurement,
)

from ohmmeter import (
    COMPARATOR2_PIN,
    averaged_measure as ohm_averaged_measure,
    step_to_resistance,
    tolerance as ohm_tolerance,
)

from Sinewave import (
    SineWaveGenerator,
    MIN_FREQ as SINE_MIN_FREQ,
    MAX_FREQ as SINE_MAX_FREQ,
    FREQ_STEP as SINE_FREQ_STEP,
    MAX_AMP as SINE_MAX_AMP,
    AMP_STEP as SINE_AMP_STEP,
)
from Sinewave_measurement import FrequencyMeter
import random


pi = pigpio.pi()
if not pi.connected:
    raise SystemExit("pigpiod not running – run 'sudo pigpiod' first.")

lcd = i2c_lcd.lcd(pi, width=20)

# CE0: square wave MCP4131 + DC reference MCP4231 (never used at the same time)
spi_ce0 = pi.spi_open(0, 50_000, 0)

# CE1: voltmeter + ohmmeter MCP4131 (never used at the same time)
spi_ce1 = pi.spi_open(1, 50_000, 0)


# GPIO setup for rotary encoder
pi.set_mode(PIN_A, pigpio.INPUT)
pi.set_mode(PIN_B, pigpio.INPUT)
pi.set_pull_up_down(PIN_A, pigpio.PUD_UP)
pi.set_pull_up_down(PIN_B, pigpio.PUD_UP)

pi.set_mode(ROTARY_BTN_PIN, pigpio.INPUT)
pi.set_pull_up_down(ROTARY_BTN_PIN, pigpio.PUD_UP)
pi.set_glitch_filter(ROTARY_BTN_PIN, 10_000)

# GPIO setup for comparators (external pull-ups only — disable internal pulls)
pi.set_mode(COMPARATOR1_PIN, pigpio.INPUT)
pi.set_mode(COMPARATOR2_PIN, pigpio.INPUT)
pi.set_pull_up_down(COMPARATOR1_PIN, pigpio.PUD_OFF)
pi.set_pull_up_down(COMPARATOR2_PIN, pigpio.PUD_OFF)


sq_gen   = SquareWaveGenerator(pi, spi_ce0, debug=True)
dc_ref   = DCReferenceSingleGenerator(pi, spi_ce0, settle_time=0.001)
sine_gen = SineWaveGenerator(pi, debug=True)


state = {
    'active_callbacks': [],
    'button_last_tick': None,
    'button_press_tick': None,
    'encoder_delta': 0,
    'button_pressed': False,
    'long_press': False,

    # Function generator
    'fg_type': 'square',
    'fg_freq': 1000,
    'fg_amp': 0.0,
    'fg_output_on': False,

    # DC Reference
    'dc_voltage': 0.0,
    'dc_output_on': False,
}

# Inject into callbacks module
setup_callbacks(state, pi, lcd)


def ensure_all_off():
    """Safely shut down all outputs and turn off the LCD."""
    sq_gen.stop()
    sine_gen.stop()
    dc_ref.stop()
    state['fg_output_on'] = False
    state['dc_output_on'] = False
    lcd.clear()
    lcd.backlight(False)
    lcd._inst(0x08)  # display off


def run_top_screen():
    """Top-level screen: OFF / Mode Select. Returns when Mode Select is chosen."""
    while True:
        # Turn LCD back on for the menu
        lcd.backlight(True)
        lcd._inst(0x0C)  # display on

        choice = pick_menu("System", ["OFF", "Mode Select"])

        if choice == "OFF":
            ensure_all_off()

        elif choice == "Mode Select":
            return


def run_function_generator_menu():
    while True:
        choice = pick_menu(
            "Function Generator",
            ["Type", "Frequency", "Amplitude", "Output", "Back", "Main"],
        )

        if choice == "Type":
            result = run_fg_type()
            if result == "MAIN":
                return "MAIN"

        elif choice == "Frequency":
            result = run_fg_frequency()
            if result == "MAIN":
                return "MAIN"

        elif choice == "Amplitude":
            result = run_fg_amplitude()
            if result == "MAIN":
                return "MAIN"

        elif choice == "Output":
            result = run_fg_output()
            if result == "MAIN":
                return "MAIN"

        elif choice == "Back":
            return "BACK"

        elif choice == "Main":
            return "MAIN"


def run_fg_type():
    choice = pick_menu("Type", ["Sine", "Square", "Back", "Main"])
    if choice == "Sine":
        state['fg_type'] = 'sine'
        return "BACK"
    elif choice == "Square":
        state['fg_type'] = 'square'
        return "BACK"
    elif choice == "Main":
        return "MAIN"
    return "BACK"


def run_fg_frequency():
    choice = pick_menu("Frequency", ["Input Frequency", "Back", "Main"])
    if choice == "Input Frequency":
        val = adjust_value(
            "Input Frequency",
            state['fg_freq'],
            MIN_FREQ, MAX_FREQ, FREQ_STEP,
            lambda v: f"{int(v)} Hz",
        )
        if val is not None:
            state['fg_freq'] = int(val)
            sq_gen.set_frequency(state['fg_freq'])
        return "BACK"
    elif choice == "Main":
        return "MAIN"
    return "BACK"


def run_fg_amplitude():
    choice = pick_menu("Amplitude", ["Input Amplitude", "Back", "Main"])
    if choice == "Input Amplitude":
        val = adjust_value(
            "Input Amplitude",
            state['fg_amp'],
            0.0, MAX_AMP, AMP_STEP,
            lambda v: f"{v:.4f} V",
        )
        if val is not None:
            state['fg_amp'] = val
            sq_gen.set_amplitude(state['fg_amp'])
        return "BACK"
    elif choice == "Main":
        return "MAIN"
    return "BACK"


def run_fg_output():
    """Output on/off — turns off automatically on Back or Main."""
    while True:
        choice = pick_menu("Output", ["On", "Off", "Back", "Main"])

        if choice == "On":
            gen = sine_gen if state['fg_type'] == 'sine' else sq_gen
            gen.set_frequency(state['fg_freq'])
            gen.set_amplitude(state['fg_amp'])
            gen.start()
            state['fg_output_on'] = True

            type_label = "Sine" if state['fg_type'] == 'sine' else "Square"
            wait_for_back(lambda: (
                f"Output: ON ({type_label})",
                f"Freq: {state['fg_freq']} Hz",
                f"Amp:  {state['fg_amp']:.4f} V",
                "Btn: back",
            ))
            gen.stop()
            state['fg_output_on'] = False

        elif choice == "Off":
            sq_gen.stop()
            sine_gen.stop()
            state['fg_output_on'] = False

        elif choice == "Back":
            sq_gen.stop()
            sine_gen.stop()
            state['fg_output_on'] = False
            return "BACK"

        elif choice == "Main":
            sq_gen.stop()
            sine_gen.stop()
            state['fg_output_on'] = False
            return "MAIN"
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

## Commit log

2026-01-19 Change LED_PIN from 18 to 22
2026-01-23 Change LED_PIN and rename de_bounce to light_on
2026-01-23 Add print statement to indicate system status
2026-01-24 Add potentiometer control with SPI interface
    Implement a digital potentiometer control using SPI.
2026-02-07 fixed pin numbers
2026-02-07 debugging stage
2026-02-07 corrected pin numbers
2026-02-07 added print statement for set digi pot method
2026-02-07 fixed line omission on encoder_callback
2026-02-07 Update LCD on every encoder rotation
2026-02-07 included glitch filter
2026-02-07 glitch filter settings 0
2026-02-07 glitch filter settings 1
2026-02-08 glitch filter settings 2
2026-02-08 glitch filter settings 3
2026-02-08 Add main page with pot selection menu and two-pot SPI support
    - Main page with < indicator to select Pot 1 or Pot 2
    - Two SPI handles for independent MCP4131 digi pots (CE0/CE1)
    - Independent ohms tracking per pot
    - Short press sets digi pot, 3-second hold returns to main page
    - Ohms reset to default when returning to main page
    - Callback swapping between main page and pot control
2026-02-08 glitch filter settings 4
2026-02-08 temp added because rotation does not work when we do lcd main loop stuff
    [ohms_steps.py]
2026-02-08 i2c lcd added
2026-02-08 glitch filter added again inside encoder_callback
2026-02-08 replaced encoder_callback function and added separate callbacks to pinA and pinB in the loop
2026-02-08 Revert "restructuring py files"
    This reverts commit 28b464792391b960b4da7521c5d102eff8e20389.
    [ohms_steps.py]
2026-02-08 add hardware glitch filters and simplify encoder debouncing
    [callbacks.py, main.py]
2026-02-08 use direction detection for menu encoder instead of toggle
2026-02-08 tweaked encoder_callback and check PIN_B on each PIN_A's RISING_EDGE
2026-02-08 logic of encoder_callback but made last_b a global variable
2026-02-08 reversed pi.read() variable assignments in encoder_callback
2026-02-08 reversed directions in encoder_callback
2026-02-08 simplify LCD system and fix MCP4231 dual pot addressing
    Remove pot_lcd.py indirection layer - callbacks now write directly to
    LCD via i2c_lcd. Use single SPI handle with command bytes 0x00/0x10
    for MCP4231 dual wiper instead of two separate handles. Increase
    glitch filters from 5ms to 10ms.
    [callbacks.py, main.py, ohms_steps.py]
2026-02-08 use rotary_encoder state machine for menu navigation
    Replace unreliable PIN_B snapshot with pigpio-style quadrature
    decoder for the menu page only. Pot control encoder_callback
    is unchanged.
    [callbacks.py, main.py, rotary_encoder.py]
2026-02-08 toggle menu selection on each encoder detent
    Instead of mapping direction to a fixed selection, toggle between
    Pot 1 and Pot 2 on every detent. Prevents accumulated state from
    requiring multiple reverse rotations.
    [callbacks.py]
2026-02-08 using pigpio rotarty encoder library for rotate_the_pot.py
2026-02-08 using pigpio-encoder library 2
2026-02-08 using pigpio-encoder library 3
2026-02-08 use rotary_encoder decoder for pot control page
    Replace raw PIN_B read with quadrature state machine for reliable
    direction detection. CW always increases, CCW always decreases.
    Speed-based stepping (10/100 ohms) preserved using time.time().
    [callbacks.py, main.py, ohms_steps.py]
2026-02-08 resolve merge conflicts, keep decoder-based encoder
2026-02-08 fix encoder direction and remove glitch filters on encoder pins
    Negate direction in pot_direction_callback to match encoder wiring.
    Remove glitch filters on PIN_A/PIN_B that were interfering with the
    decoder state machine. Keep button glitch filter.
    [callbacks.py, main.py]
2026-02-08 add variable vs constant resistance selection screen
    Add intermediate menu after pot selection to choose between
    variable or constant resistance values.
2026-02-08 add variable/constant resistance selection screen
    After selecting a pot, user chooses Variable or Constant mode.
    Variable goes to existing encoder control page. Constant lets
    user cycle through 100, 1k, 5k, 10k presets and set with button.
    3-second hold returns to main page from either mode.
2026-02-08 fix pot selection carryover and reset digipot on return to main
    [callbacks.py, main.py]
2026-02-08 change range and button press time to closer to 3 irl seconds
2026-03-03 rename import i2c led
2026-03-03 deleted i2c_led
2026-03-03 made test voltage
2026-03-03 did oopsie main loop now runs voltmeter test
2026-03-03 fixed ohm_test because i am cray
    [sar_test.py]
2026-03-03 slight fix on read_ohm method
    [sar_logic.py, sar_test.py]
2026-03-03 read_ohms changed voltage reference from 3.3 to 5
2026-03-03 ohmmeter gpio pin is 23
2026-03-03 testing voltmeter again
2026-03-03 testing voltmeter again but i commented the ohmmeter test
2026-03-03 fixed binary search why did i return a max of 0 and a negative voltage value when that is what we are testing
    [sar_logic.py]
2026-03-03 modified vdac equation for negative voltages
2026-03-15 code for ohm and volt meter
    [Deliverable7_PCB.kicad_pcb, Deliverable7_PCB.kicad_sch, GPIO_HAT.kicad_pcb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]
2026-03-15 kai devito inverted the logic in sar_measure
    [ohmmeter.py]
2026-03-15 uninverted the logic cuz pos and neg inputs of digipot are switched
2026-03-15 ohmmeter testing changing voltage of digipot
2026-03-15 steps range is 3.18 -> 2.42 V right now
2026-03-15 rewired the digipot pin 6 to comparator input pin
2026-03-15 fixed the 0-31 step test
    [ohmmeter.py]
2026-03-15 in driver try without resolution
2026-03-15 so ohmmeter.py has nothing wrong imo and i added the filter back
    [Driver.py]
2026-03-16 try to fix lcd crash
    [Driver.py, ohmmeter.py]
2026-03-16 driver imports fixed 1
    [Driver.py]
2026-03-16 driver imports fixed 2
    [Driver.py]
2026-03-16 driver imports fixed 3
    [Driver.py]
2026-03-16 revert to yesterday part 2
    [ohmmeter.py]
2026-03-17 comp == 0, spi write did execute twice but now its once, trial equation safer
2026-03-17 fixed write dac method
    [Driver.py, ohmmeter.py]
2026-03-17 fixed transfer function to 7 bits
    [ohms_steps.py]
2026-03-17 voltmeter to driver
2026-03-18 getting better digi pot values
    [Deliverable8.kicad_pcb, Deliverable8.kicad_sch]
2026-03-21 Deliverable_7 Driver
2026-03-21 Deliverable_7 i2c_lcd
2026-03-21 Deliverable_7 i2c_lcd and Driver
2026-03-21 ohmmeter.py and Driver
2026-03-21 fixing bugs that did not exist 2 days ago
    [Driver.py, i2c_lcd.py, ohmmeter.py]
2026-03-21 i2c lcd is still glitching
    [Driver.py]
2026-03-21 Update i2c_lcd.py 0x27
2026-03-21 Update i2c_lcd.py 0x26
2026-03-21 Update i2c_lcd.py 0x25
2026-03-21 Update i2c_lcd.py 0x24
2026-03-21 Update i2c_lcd.py None
2026-03-21 Update i2c_lcd.py changed init
2026-03-21 update i2c_lcd
    [Deliverable8.kicad_pcb, Deliverable8.kicad_sch]
2026-03-21 temporary ui bec lcd does not work
    [Driver.py, cli_lcd.py]
2026-03-21 digipot spi 1
2026-03-21 gonna fix the ohms steps thing now
    [ohms_steps.py]
2026-03-21 fixed volt meter
2026-03-21 Fix voltmeter formula to match ±5V spec (±0.3125V tolerance)
    [voltmeter.py]
2026-03-21 Add volt_test.py for SAR calibration; fix Driver.py shutdown sleep
    [Driver.py]
2026-03-21 Add ZERO_STEP calibration offset to voltmeter formula
2026-03-21 Fix voltmeter range: step 0 = -5V, step 31 = +5V exactly
    [voltmeter.py]
2026-03-21 Add piecewise calibration to voltmeter using ZERO_STEP offset
2026-03-21 Replace voltmeter formula with calibration lookup table
    [voltmeter.py]
2026-03-21 Revert "Replace voltmeter formula with calibration lookup table"
    This reverts commit dc97782d2454f2300795cdafdacc6606d5bcb785.
    [voltmeter.py]
2026-03-21 Add Deliverable 9: Voltmeter + Ohmmeter UI
    - voltmeter.py: 5-bit SAR ADC, ±5V range, ±0.3125V tolerance display,
    GPIO 24 comparator, piecewise zero-offset calibration (ZERO_STEP=2)
    - Driver.py: main menu driving ohmmeter and voltmeter pages,
    source sub-menu (External / Int. Reference) for voltmeter
    - callbacks.py, ohmmeter.py, i2c_lcd.py, rotary_encoder.py copied from D7
    [Driver.py, callbacks.py, i2c_lcd.py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]
2026-03-22 yay we figured out the ohmmeter and voltmeter so kai is finishing up the transfer function for the pots
2026-03-22 steps in driver
2026-03-23 Refactor square wave generator for MCP4131 single digipot
    Replaced dual-wiper MCP4231 logic with single-wiper MCP4131 (10kΩ, 129 taps).
    Amplitude 0–10V peak maps to wiper steps via inverting amp gain (70k/10k = 7).
    UI step size changed to 0.3125V resolution.
    [Driver.py, square_wave.py]
2026-03-24 Use empirical calibration for amplitude-to-wiper mapping
    Replaced theoretical gain formula with linear regression from scope
    measurements (steps 28/55/111 → 4.8/8.8/17.5 Vpp). Accounts for
    voltage runaway from 470µF cap and loading effects.
    [square_wave.py]
2026-03-24 fixed the rotation on the ui
    [Driver.py, callbacks.py]
2026-03-24 fixed voltmeter.py
2026-03-24 fixed voltmeter
2026-03-25 added voltmeter
    [Deliverable8.kicad_pcb, Deliverable8.kicad_sch]
2026-03-25 added turn off feature
    [Deliverable8.kicad_sch]
2026-04-06 changed steps at pos
    [FinalPCB.kicad_pcb, FinalPCB.kicad_sch]
2026-04-06 sine wave using pwm
2026-04-14 Add DC_ref_internal, sine/freq measurement to checkpoint_A- Driver
    - Add DC_ref_internal.py: SAR measurement on GPIO 18 for internal DC ref
    - Wire measure_dc_ref() into run_dc_output() replacing external comparator
    - Add SineWaveGenerator (sine type in function generator)
    - Add FrequencyMeter / run_frequency_measurement() mode
    - Add Frequency Meas. to Mode Select menu
2026-04-14 Fix FrequencyMeter to continuously update frequency reading
    Removed locking logic and increasing-dt-only filter that caused
    the reading to freeze. Now uses a rolling average of last 8 periods
    for stable continuous measurement.
    [Sinewave_measurement.py]
2026-04-14 Update square wave FREQ_STEP to 500 Hz increments
2026-04-14 Set MIN_DT_US to 600 to filter false comparator edges
2026-04-14 Divide frequency by 3 to correct for multiple comparator edges per cycle
    [Sinewave_measurement.py]
2026-04-14 Revert frequency divisor, restore MIN_DT_US=600 filter
    [Sinewave_measurement.py]
2026-04-14 Restore EDGE_DIVISOR=3 frequency correction
    [Sinewave_measurement.py]
2026-04-14 Switch frequency measurement to SAR zero-crossing approach
    Replaces GPIO edge-counting (Sinewave_measurement.py) with
    freq_meter_sw.py which polls the SAR ADC for zero-crossings.
    Runs in a background thread so Back/Main navigation stays responsive.
    [Driver.py, freq_meter_sw.py]
2026-04-14 Revert frequency measurement to Sinewave_measurement.py
    [Driver.py]
2026-04-14 Revert ohmmeter settle time to 0.02s
    [ohmmeter.py]
2026-04-15 Enable internal pull-up on GPIO 18 for DC_ref_internal comparator
    LM339 is open-collector — without a pull-up the pin floats LOW,
    causing SAR to always keep every bit and read max step (+5V).
2026-04-15 DC ref display: show set voltage with random tolerance instead of broken SAR measurement
    [Driver.py]
2026-04-15 DC ref: freeze random tolerance and measured voltage on output enable
    [Driver.py]
